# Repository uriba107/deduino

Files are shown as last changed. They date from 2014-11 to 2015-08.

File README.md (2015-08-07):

# DEDUino
Arduino Based DED for Falcon BMS.
Project Blog: http://pits.108vfs.org

## Requirements:
### Hardware:
1. an Arduino or compatible board:
  * Arduino Uno (or compatible)
  * Arduino Micro (or compatible)
  * Arduino Due (or compatible)
  * all similar Arduino/Arduino-like variations (Mega/leonardo/pro Micro) will require code to be adjusted
2. For DED/PFL: One 2.8" or 3.2" 256*64 OLED display (yellow or green), SSD1322 based
  * [BuyDisplay 2.8" yellow on black oled](http://www.buydisplay.com/default/spi-2-8-inch-oled-arduino-256x64-graphic-module-with-pcb-yellow-on-black)
  * [BuyDisplay 3.2" green on black oled](http://www.buydisplay.com/default/spi-oled-manufacturer-256x64-display-panel-supplier-green-on-black)
  * other screens may be also compatible (as long as they are SSD1322 based) - but may require different wiring.
3. For FFI: one 1.3" 128*64 OLED white on black. SSD1306 or SH1106 based
  * [Adafruit 1.3" 128*64 OLED](http://www.adafruit.com/product/938)
  * Generic 1.3" OLED (off the internet), will do fine as long as it's of one of the supported chipsets.
  * Other displays might be also compatible - but may require code edit
4. For Indexers/Caution panel:
  * [PCF8574 8-bit I2C I/O Expander](http://www.ebay.com/sch/sis.html?_nkw=PCF8574P+PCF8574+DIP-16+NXP%2FPHI+Remote+8-bit+I%2FO+Expander+IC) - for Indexers
  * [MCP23017 16-bit I2C I/O Expander](http://www.ebay.com/sch/sis.html?_nkw=MCP23017-E%2FSP+DIP28+16-Bit+I%2FO+Expander+with+I2C+Interface+IC) - optional 16 bit extender (useful for caution panel and other things)
  * LEDs of your choosing (If using attached PCB design unmodified - 5mm pirahna leds are used)
  * Resistors (220-330 ohm reesistors would be a good place to start)
  * Legacy SPI lights are using [74HC595 Shift Register](http://www.adafruit.com/product/450) - you can find them on ebay as well.

### Software:
1. Arduino IDE
2. Windows Vista and up with .net 4.5 installed (XP does not support .net4.5 and I've not tested the supplied connector app with .net4.0)
3. Falcon BMS 4.32+

## How to use:
### Initial setup:
1. Download and install the Arduino IDE (if not already installed)
2. Download the Arduino code
3. In the Arduino IDE - "Add library" choose "U8glib_DEDuino" it's standard U8glib 1.18.1 with 16BIT support enabled (required for the large displays)
4. In "config.h" and uncomment the correct define for your arduino version (Uno, Micro or Due).
5. In "config.h" Uncomment the define statements for the periferials you want to use. please note that adding both DED and PFL may have an impact on performace.
6. Wire prereferials according the the pinout in the code. Please pay attention to the SCK and MOSI pins and the latchpins
7. Upload code to your Arduino.
8. Download the DEDuino Windows app and place it in a folder of your choosing (no installation required)

### running the project:
1. launch DEDuino App
2. Select proper COM port for the arduino to be used and hit "Start"
3. Once connected - Windows app will indicate connected status and all displays and leds should be blanked except for FFI screen that will show "00000".
4. Launch Falcon BMS - As soon as you enter the cockpit, all the instruments connected should display acording to the pit.

## Supported instruments:
1. Displays:
  * DED - Tier 1
  * FFI - Tier 1
  * PFD - Tier 1 (disabled by default due to performance considuration)
2. Lights:
  * Indexers - Tier 1
  * Caution Panel - Tier 1 (Disabled by default due to performance consideration)
3. Future supported instruments:
  * Glareshield lighs - TBD
  * Threat Warning Prime - TBD
  * CMDS - via OLED screen, TBD

## Knows issues:
1. Activating more the one large res display (DED/PFD) will cause performace degradation. Activating more then two might cause noticable lag without further optimization to Arduino code (not yet implemented).
2. "lamp test" might not work properly for Caution panel is some scenarios.
3. When using SPI for driving multiple light arrays, there are issues including freezes, wrongly timed blinks and all sort of wierd shananigans. That is way, I2C is now the primary, prefered protocol for driving lights. SPI support will not be extended, and only retained for comptability.

## PCB
In the PCB folder you would find Eagle files and PDFs with schematics and board drawings. These are the boards I'm working with. You can make them yourself by hand soldering the connectors (see schematics) or source them out to production. All boards were edited using the Free version of Eagle (version 7).

## Enclosures
In the "enclosure" folders you'll find some stractual stuff, like the foamboard DED box.

## Notes and remarks
While the project is OpenSource. Currently I'm holding back the source code for the PC connector application. That is done because The code is a mess, I need to properly document it before I release it. Hopfully sometime this year. Nothing secret about it, promise :)

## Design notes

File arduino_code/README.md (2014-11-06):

## DEDuino - Arduino code
This Is the Arduino side of the project, Licensed under MIT license.

### Usage:
The code contain define statemenst for the three supported Arduino (UNO, Micro and Due).
The code also contains define statmens to all supported featues in this version
#### Available features:
  * Displays: DED, FFI, PFD
  * Lights: Indexers, Caution Panel

#### Default settings (enabled by default):
  * Arduino Uno
  * Displays: DED, FFI
  * Lights: Indexers

#### Known issues:
  * you cannot corrently activate both indexers and caution panel - probably due to the lack of a pull up resistor somewhere. 
  * Lights do not work properly on Due - probably due to a electric design problem - will be solved in future revision.

### Note:
  * Check corresponding wiring diagram in the folder - adjust if needed.
  * Project is using Hardware SPI for best performance - please note that some pins are hardware limited

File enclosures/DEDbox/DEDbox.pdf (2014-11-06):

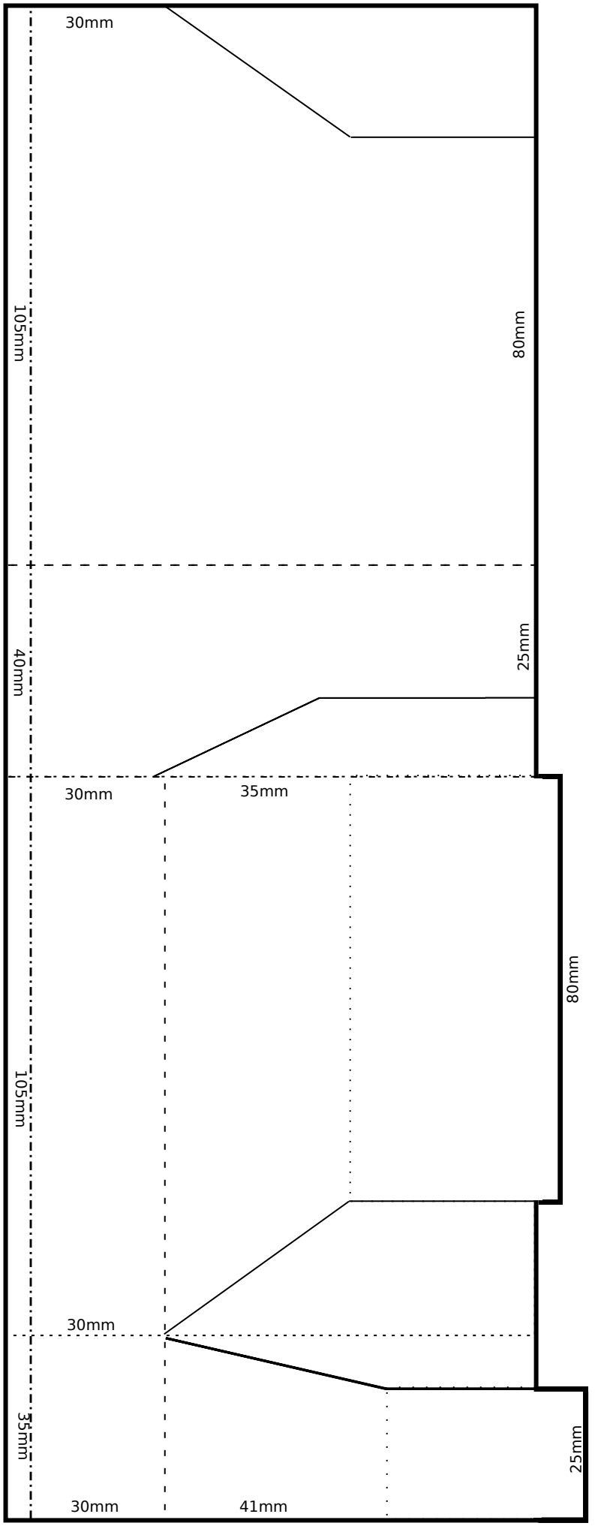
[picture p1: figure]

100mm

285mm

5mm black foamboard

# DED Box

Uri Ben-Avraham 2014

Cut
Folded
(inner)
Folded
(Outer)
Groove

## Legend

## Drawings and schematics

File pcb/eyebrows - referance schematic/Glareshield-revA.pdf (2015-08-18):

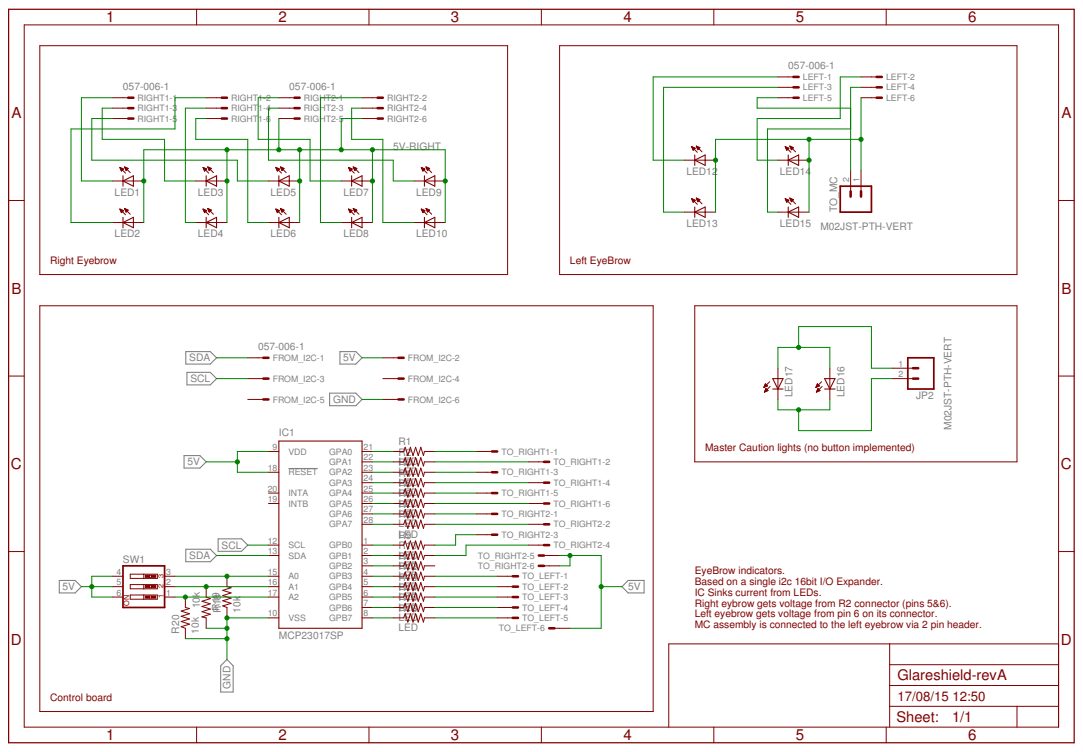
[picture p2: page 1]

Master Caution lights (no button implemented)

IC Sinks current from LEDs. Right eybrow gets voltage from R2 connector (pins 5&6). Left eyebrow gets voltage from pin 6 on its connector. MC assembly is connected to the left eyebrow via 2 pin header. 1 2 3 ON

EyeBrow indicators. Based on a single i2c 16bit I/O Expander.

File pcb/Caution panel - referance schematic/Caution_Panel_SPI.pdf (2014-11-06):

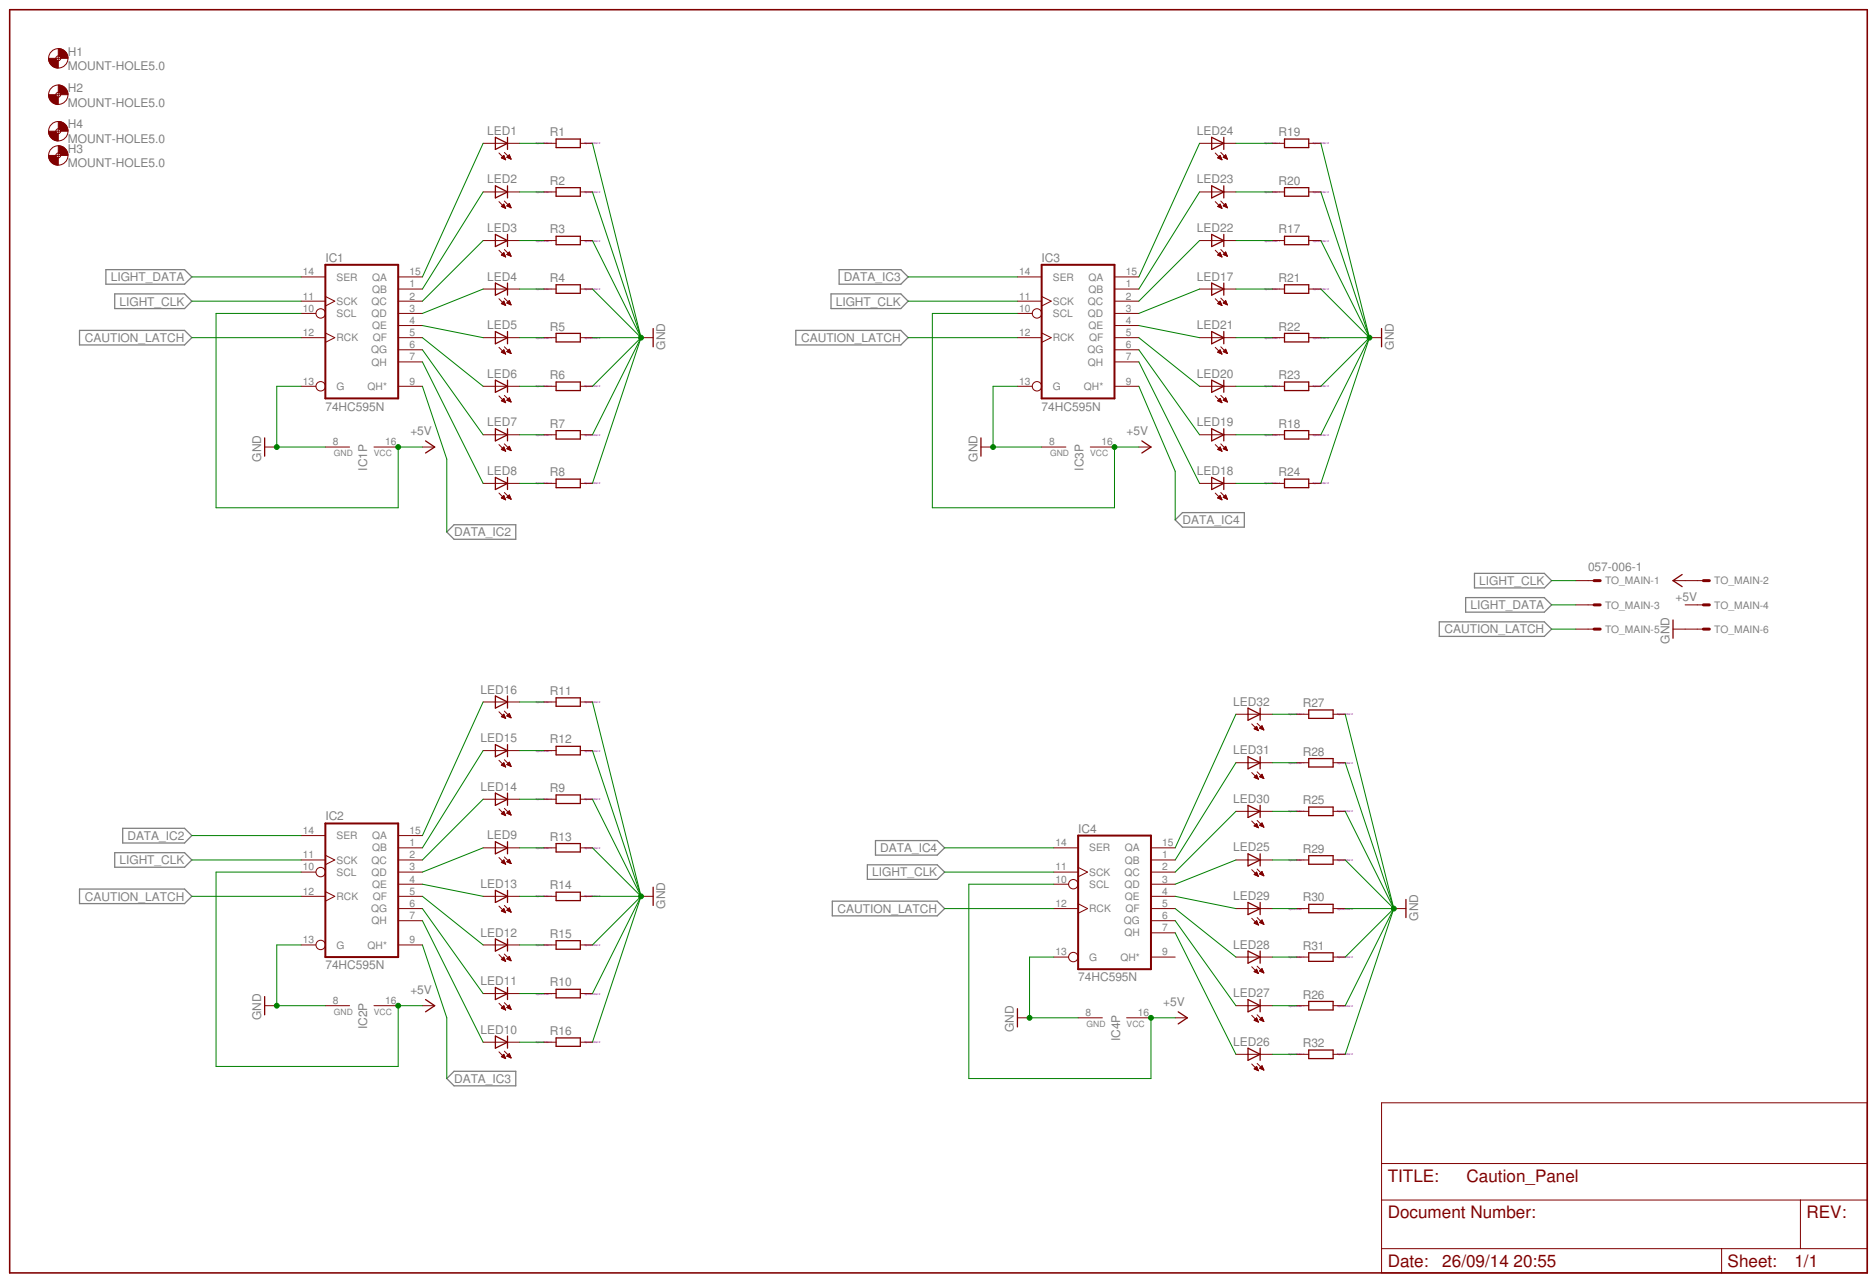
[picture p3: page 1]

MOUNT-HOLE5.0 MOUNT-HOLE5.0

REV: TITLE: Document Number: Caution_Panel

Date: 26/09/14 20:55 | Sheet: 1/1

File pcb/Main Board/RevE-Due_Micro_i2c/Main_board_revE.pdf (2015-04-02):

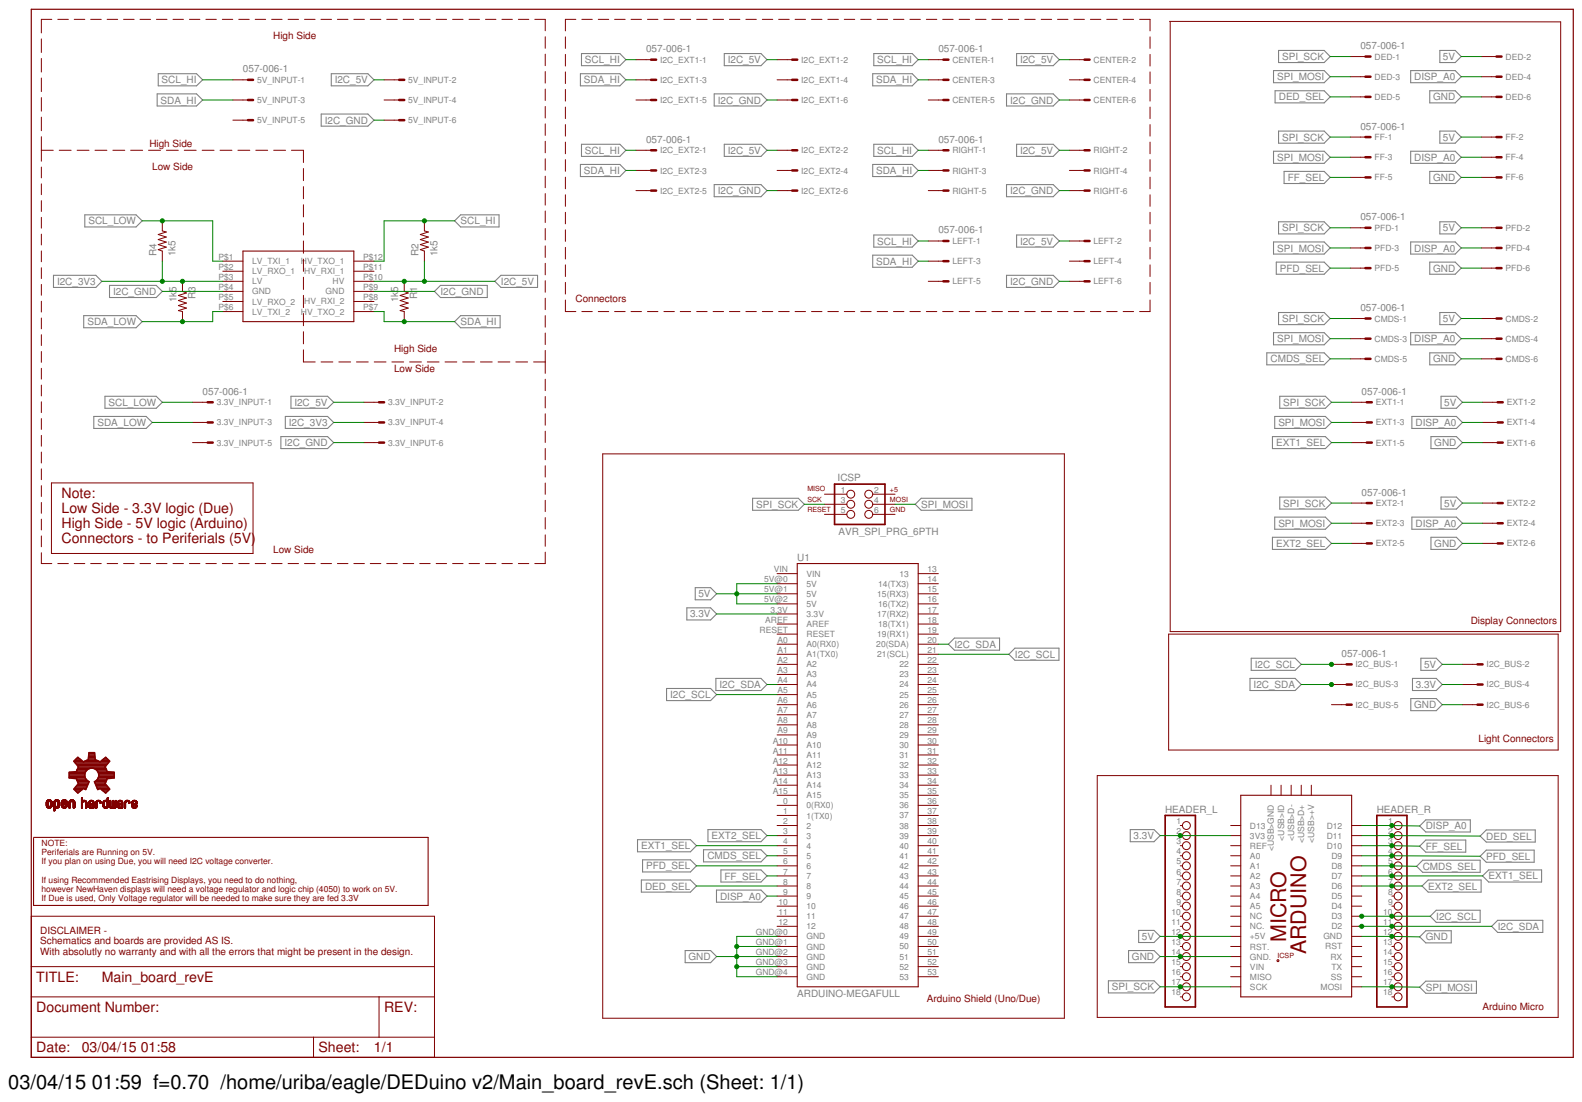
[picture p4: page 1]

Low Side High Side

Note: Low Side - 3.3V logic (Due)
High Side - 5V logic (Arduino)
Connectors - to Periferials (5V)

NOTE: Periferials are Running on 5V.
If you plan on using Due, you will need I2C voltage converter.
If using Recommended Eastrising Displays, you need to do nothing, however NewHaven displays will need a voltage regulator and logic chip (4050) to work on 5V.
If Due is used, Only Voltage regulator will be needed to make sure they are fed 3.3V

DISCLAIMER - Schematics and boards are provided AS IS. With absolutly no warranty and with all the errors that might be present in the design.

REV: TITLE: Document Number: Main_board_revE

Date: 03/04/15 01:58 | Sheet: 1/1

03/04/15 01:59 f=0.70 /home/uriba/eagle/DEDuino v2/Main_board_revE.sch (Sheet: 1/1)

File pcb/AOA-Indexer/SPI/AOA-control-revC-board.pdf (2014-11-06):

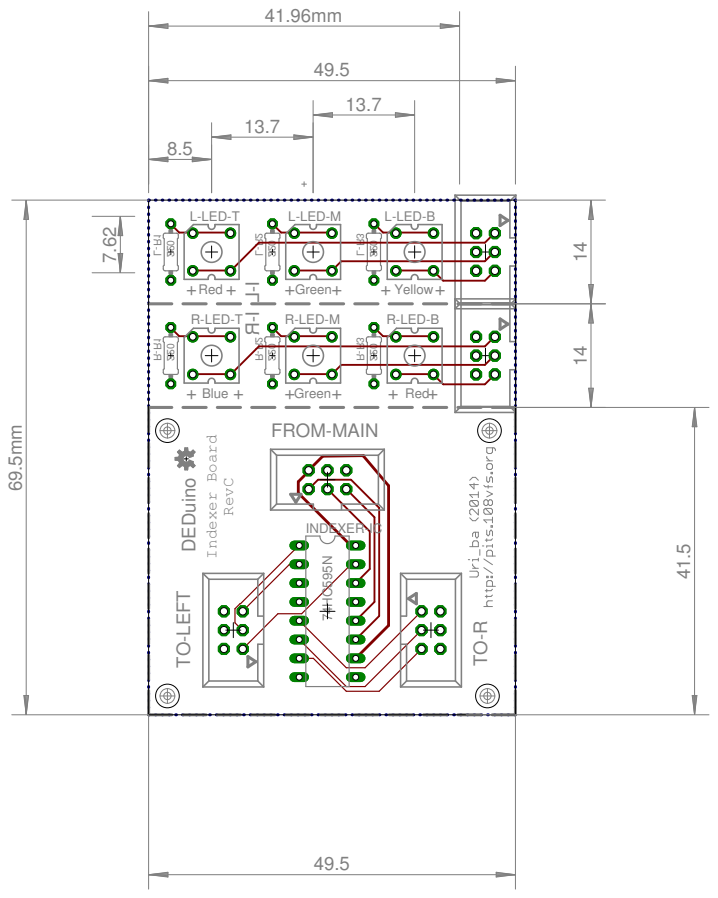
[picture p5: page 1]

220 220 220 220 220 220 I-L L-R1 I-R R-R1 R-R2 R-R3 L-R2 L-R3 + + + + + + + + + + + + Indexer Board RevC DEDuino FROM-MAIN TO-LEFT TO-R INDEXER-IC L-LED-T L-LED-M L-LED-B R-LED-T R-LED-M R-LED-B 74HC595N Red Green Yellow Blue Green Red 41.5 49.5 14 14 69.5mm 8.5 13.7 49.5 7.62 41.96mm 13.7

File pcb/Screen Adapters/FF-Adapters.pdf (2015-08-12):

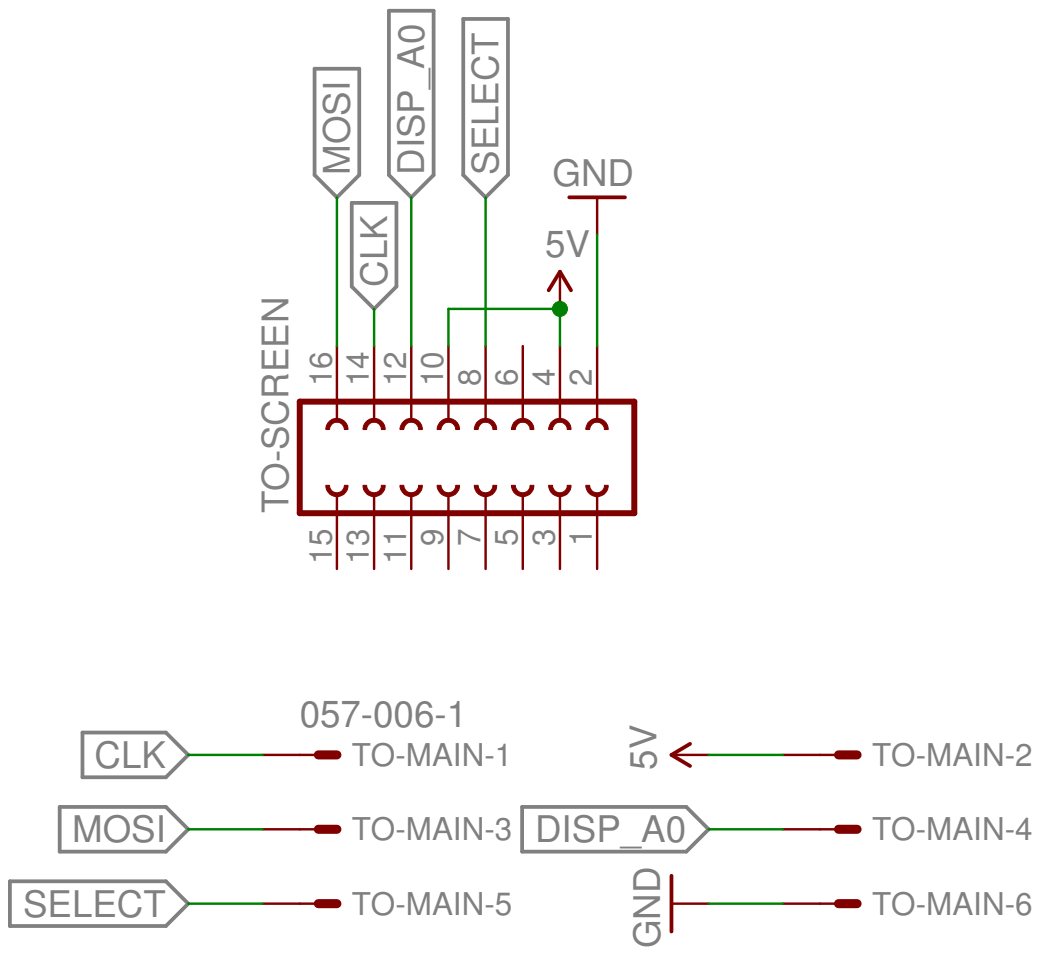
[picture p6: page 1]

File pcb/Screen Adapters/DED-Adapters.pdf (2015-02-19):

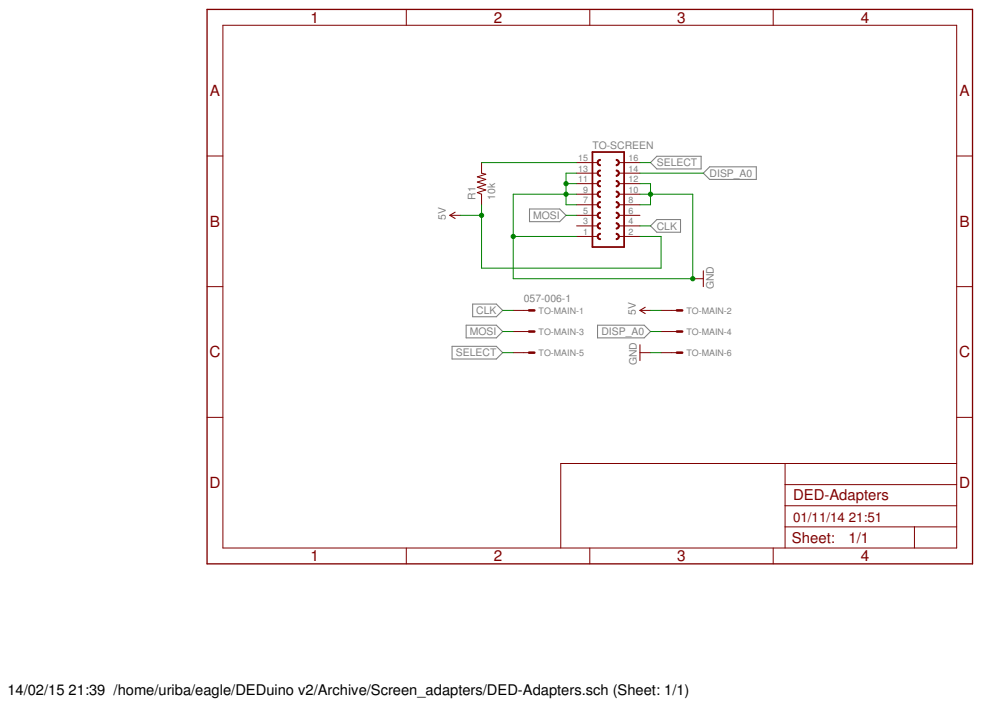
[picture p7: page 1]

10k TO-MAIN-1 TO-MAIN-2 TO-MAIN-3 TO-MAIN-4 TO-MAIN-5 TO-MAIN-6

14/02/15 21:39 /home/uriba/eagle/DEDuino v2/Archive/Screen_adapters/DED-Adapters.sch (Sheet: 1/1)

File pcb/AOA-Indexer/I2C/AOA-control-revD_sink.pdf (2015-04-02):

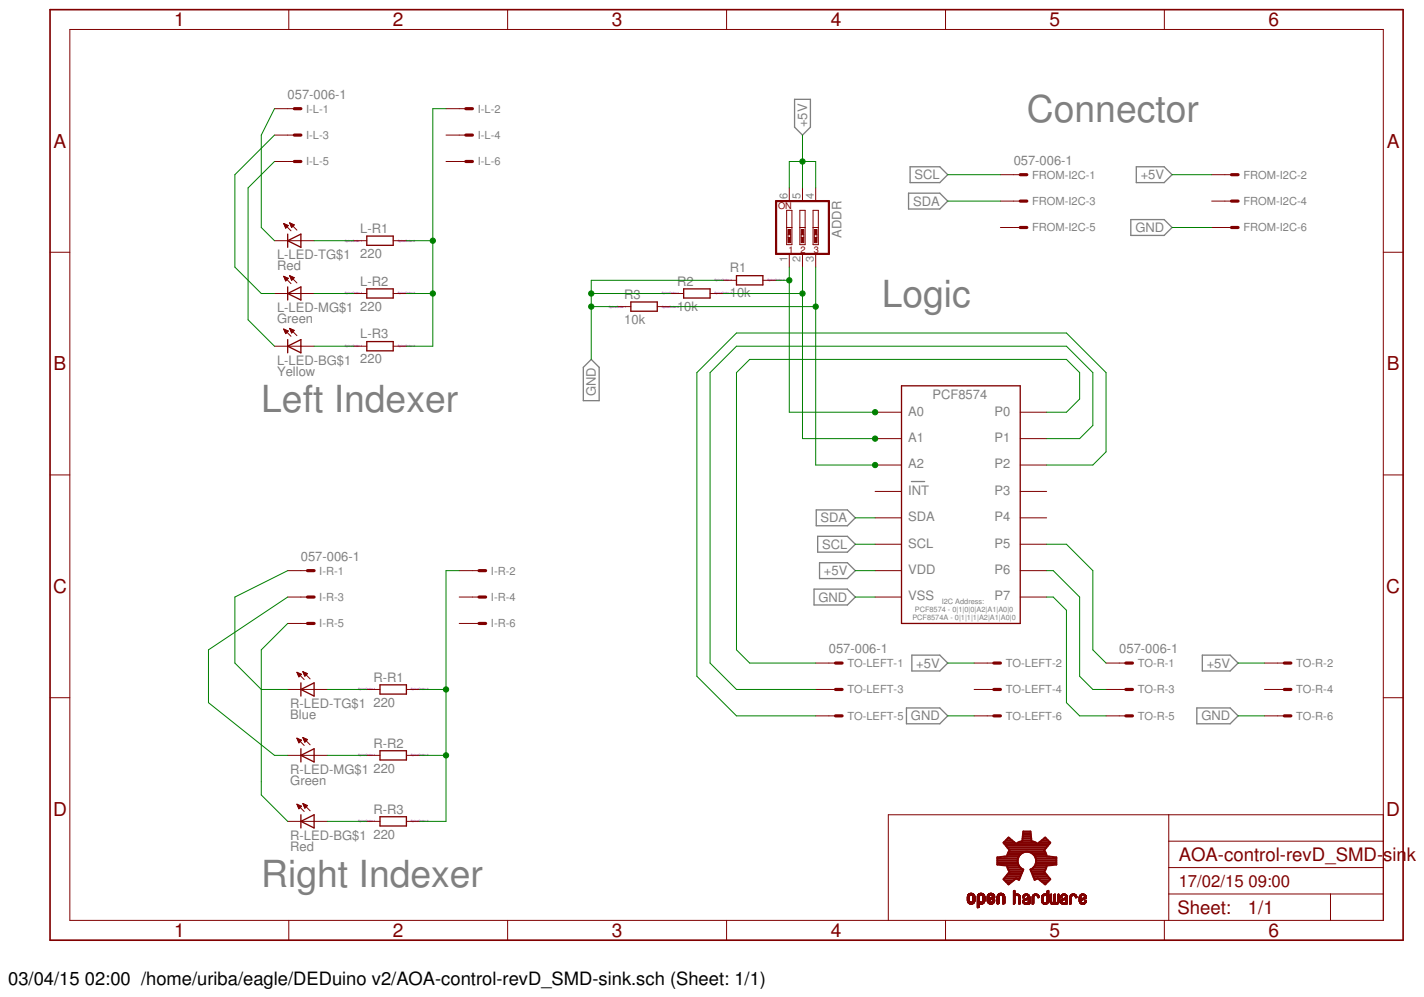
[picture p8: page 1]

03/04/15 02:00 /home/uriba/eagle/DEDuino v2/AOA-control-revD_SMD-sink.sch (Sheet: 1/1)

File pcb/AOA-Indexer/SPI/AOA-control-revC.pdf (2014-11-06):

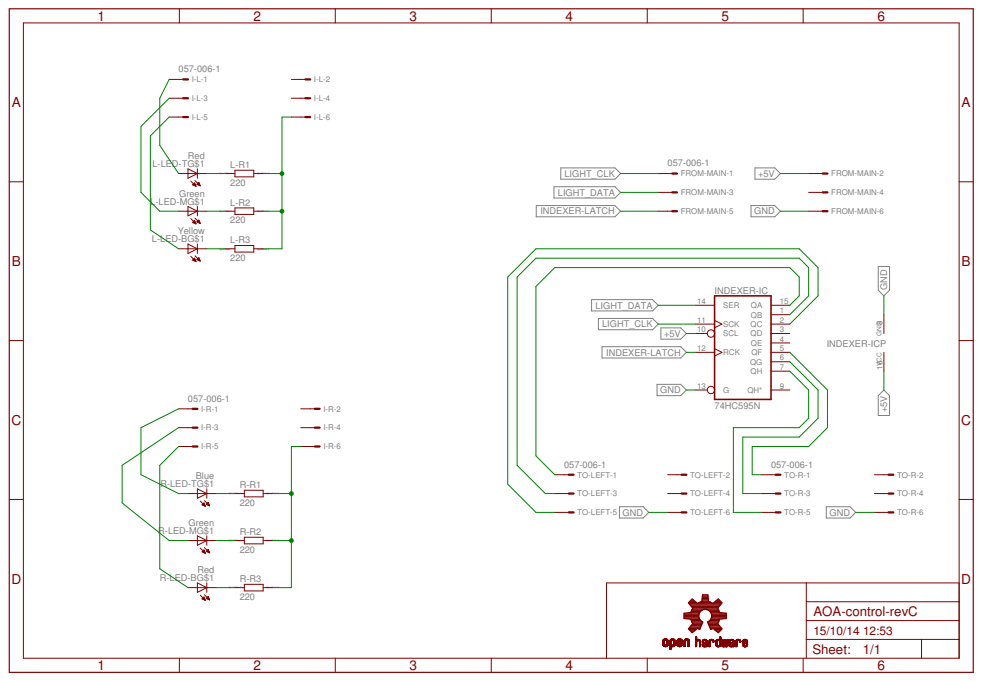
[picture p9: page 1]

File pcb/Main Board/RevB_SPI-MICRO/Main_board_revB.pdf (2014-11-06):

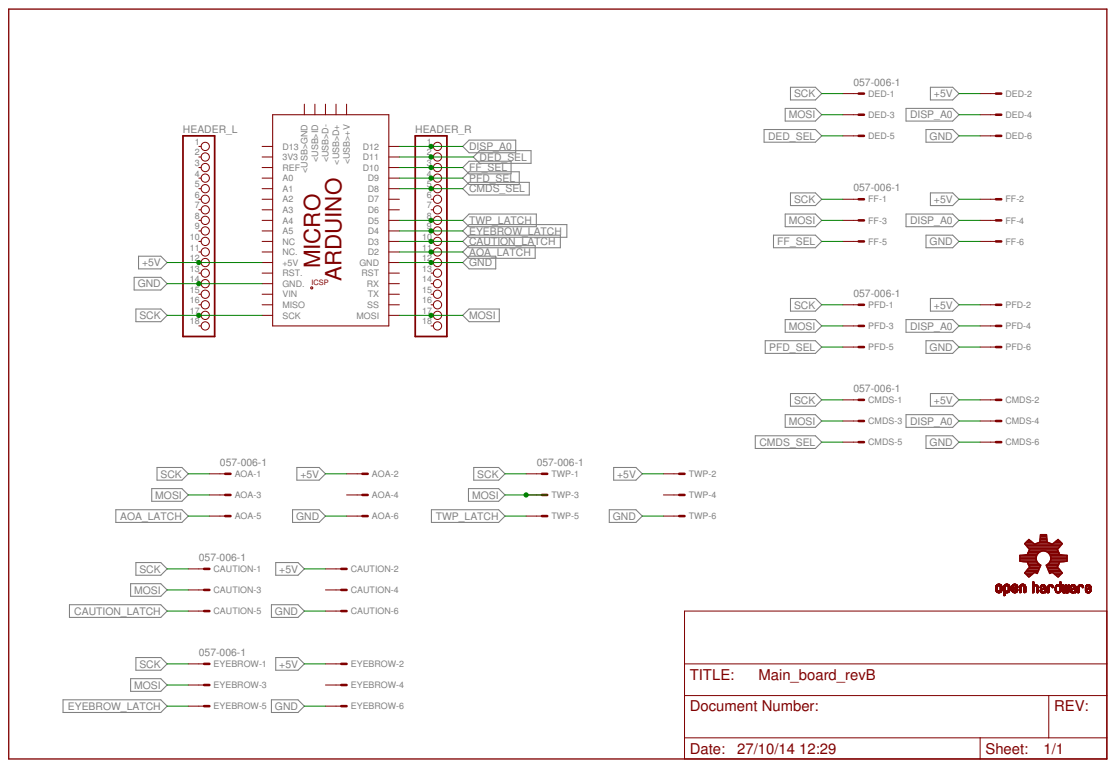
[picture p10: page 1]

3 4 5 6 7 8 9 10 11 12 13 14 15 16 17 18 | DED_SEL

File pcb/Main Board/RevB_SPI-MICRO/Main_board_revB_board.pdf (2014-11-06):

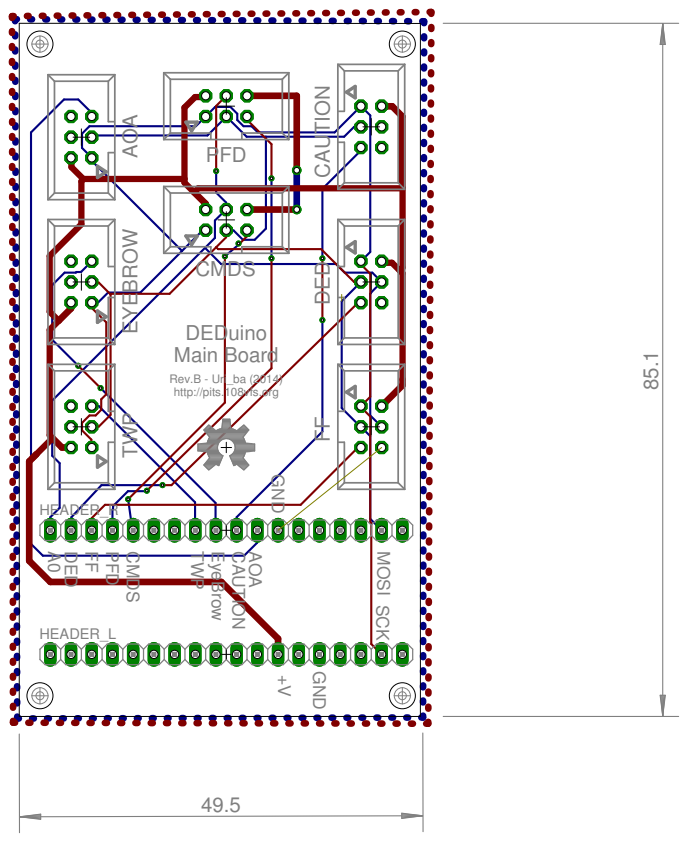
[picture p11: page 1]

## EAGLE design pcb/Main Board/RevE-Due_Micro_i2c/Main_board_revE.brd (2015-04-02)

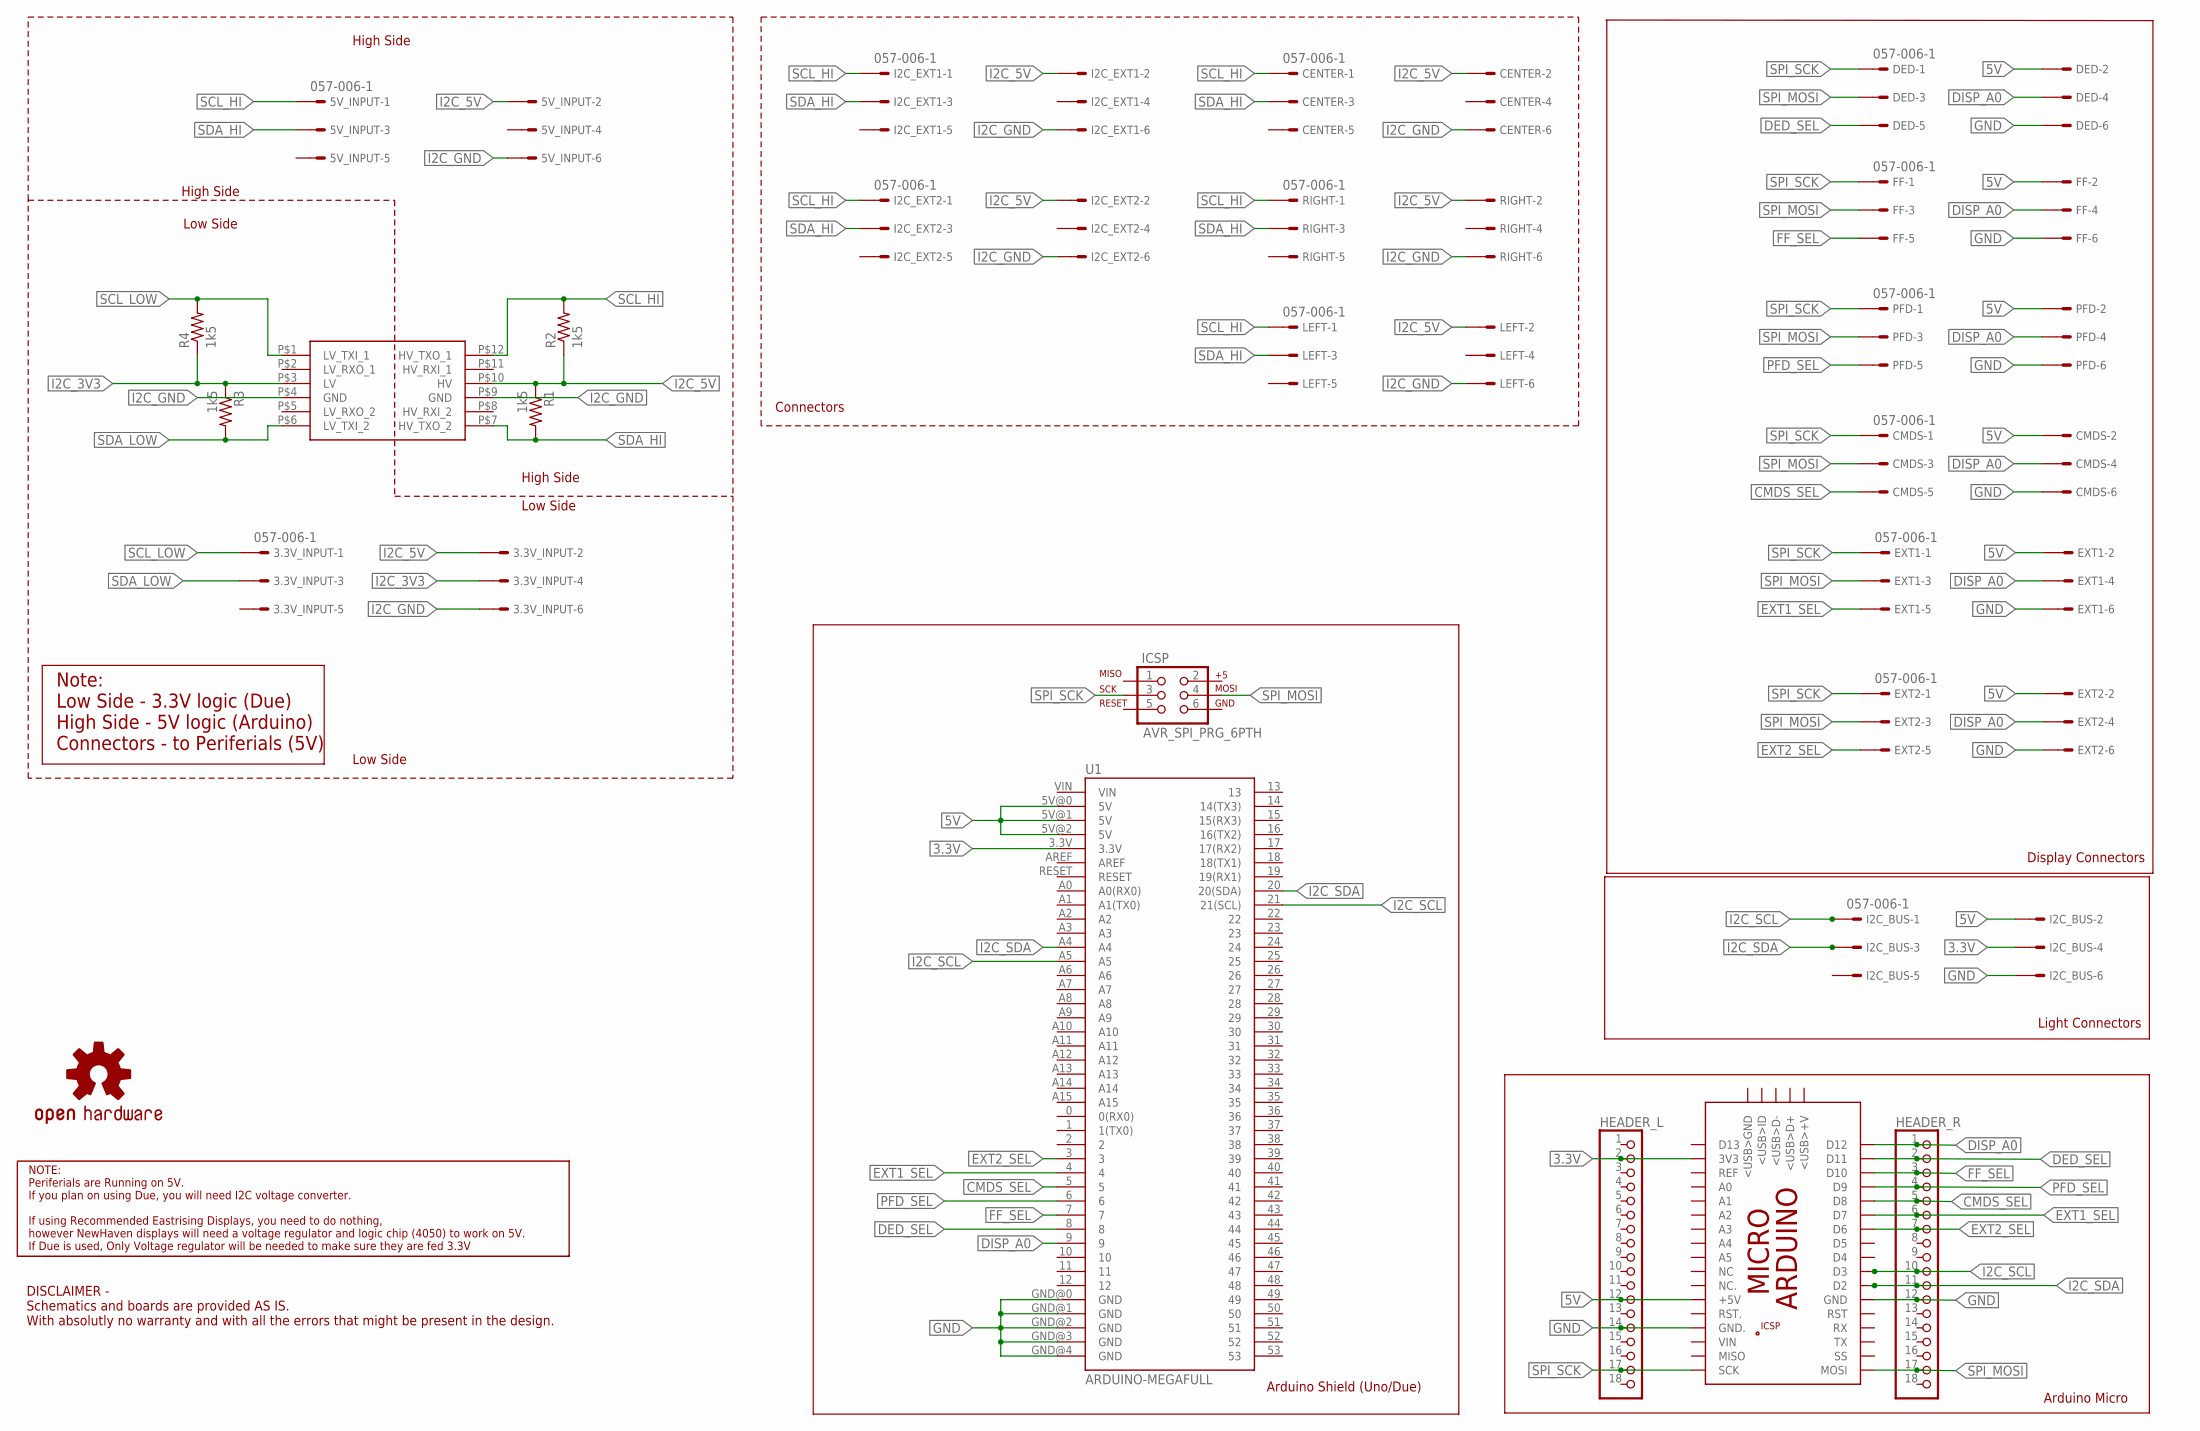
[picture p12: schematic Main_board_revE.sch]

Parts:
3.3V_INPUT, 5V_INPUT: 057-006-1
CENTER: 057-006-1
CMDS: 057-006-1
DED: 057-006-1
EXT1, EXT2: 057-006-1
FF: 057-006-1
HEADER_L: PINHD-1X18; 1X18
HEADER_R: PINHD-1X18; 1X18
I2C_BUS, I2C_EXT1, I2C_EXT2: 057-006-1
ICSP: AVR_SPI_PRG_6PTH; 2X3
LEFT: 057-006-1
LOGO1: OSHW-LOGOM; OSHW-LOGO-M
PFD: 057-006-1
R1, R2, R3, R4: 1k5; 0805
RIGHT: 057-006-1
U1: ARDUINO-MEGAFULL; ARDUINO_MEGA
U$1: LOGIC_LEVEL_CONVERTER

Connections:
3.3V: HEADER_L.2, I2C_BUS.4, U1.3.3V
5V: CMDS.2, DED.2, EXT1.2, EXT2.2, FF.2, HEADER_L.12, I2C_BUS.2, PFD.2, U1.5V@0 (5V), U1.5V@1 (5V), U1.5V@2 (5V)
CMDS_SEL: CMDS.5, HEADER_R.5, U1.5
DED_SEL: DED.5, HEADER_R.2, U1.8
DISP_A0: CMDS.4, DED.4, EXT1.4, EXT2.4, FF.4, HEADER_R.1, PFD.4, U1.9
EXT1_SEL: EXT1.5, HEADER_R.6, U1.4
EXT2_SEL: EXT2.5, HEADER_R.7, U1.3
FF_SEL: FF.5, HEADER_R.3, U1.7
GND: CMDS.6, DED.6, EXT1.6, EXT2.6, FF.6, HEADER_L.14, HEADER_R.12, I2C_BUS.6, PFD.6, U1.GND@0 (GND), U1.GND@1 (GND), U1.GND@2 (GND), U1.GND@3 (GND), U1.GND@4 (GND)
I2C_3V3: 3.3V_INPUT.4, R3.1, R4.1, U$1.P$3 (LV)
I2C_5V: 3.3V_INPUT.2, 5V_INPUT.2, CENTER.2, I2C_EXT1.2, I2C_EXT2.2, LEFT.2, R1.1, R2.1, RIGHT.2, U$1.P$10 (HV)
I2C_GND: 3.3V_INPUT.6, 5V_INPUT.6, CENTER.6, I2C_EXT1.6, I2C_EXT2.6, LEFT.6, RIGHT.6, U$1.P$4 (GND), U$1.P$9 (GND)
I2C_SCL: HEADER_R.10, I2C_BUS.1, U1.21 (21(SCL)), U1.A5
I2C_SDA: HEADER_R.11, I2C_BUS.3, U1.20 (20(SDA)), U1.A4
PFD_SEL: HEADER_R.4, PFD.5, U1.6
SCL_HI: 5V_INPUT.1, CENTER.1, I2C_EXT1.1, I2C_EXT2.1, LEFT.1, R2.2, RIGHT.1, U$1.P$12 (HV_TXO_1)
SCL_LOW: 3.3V_INPUT.1, R4.2, U$1.P$1 (LV_TXI_1)
SDA_HI: 5V_INPUT.3, CENTER.3, I2C_EXT1.3, I2C_EXT2.3, LEFT.3, R1.2, RIGHT.3, U$1.P$7 (HV_TXO_2)
SDA_LOW: 3.3V_INPUT.3, R3.2, U$1.P$6 (LV_TXI_2)
SPI_MOSI: CMDS.3, DED.3, EXT1.3, EXT2.3, FF.3, HEADER_R.17, ICSP.4, PFD.3
SPI_SCK: CMDS.1, DED.1, EXT1.1, EXT2.1, FF.1, HEADER_L.17, ICSP.3, PFD.1

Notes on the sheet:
Arduino Shield (Uno/Due)
Arduino Micro
Light Connectors
Display Connectors
DISCLAIMER - Schematics and boards are provided AS IS. With absolutly no warranty and with all the errors that might be present in the design.
NOTE: Periferials are Running on 5V. If you plan on using Due, you will need I2C voltage converter. If using Recommended Eastrising Displays, you need to do nothing, however NewHaven displays will need a voltage regulator and logic chip (4050) to work on 5V. If Due is used, Only Voltage regulator w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
Low Side
High Side
Connectors
Note: Low Side - 3.3V logic (Due) High Side - 5V logic (Arduino) Connectors - to Periferials (5V)

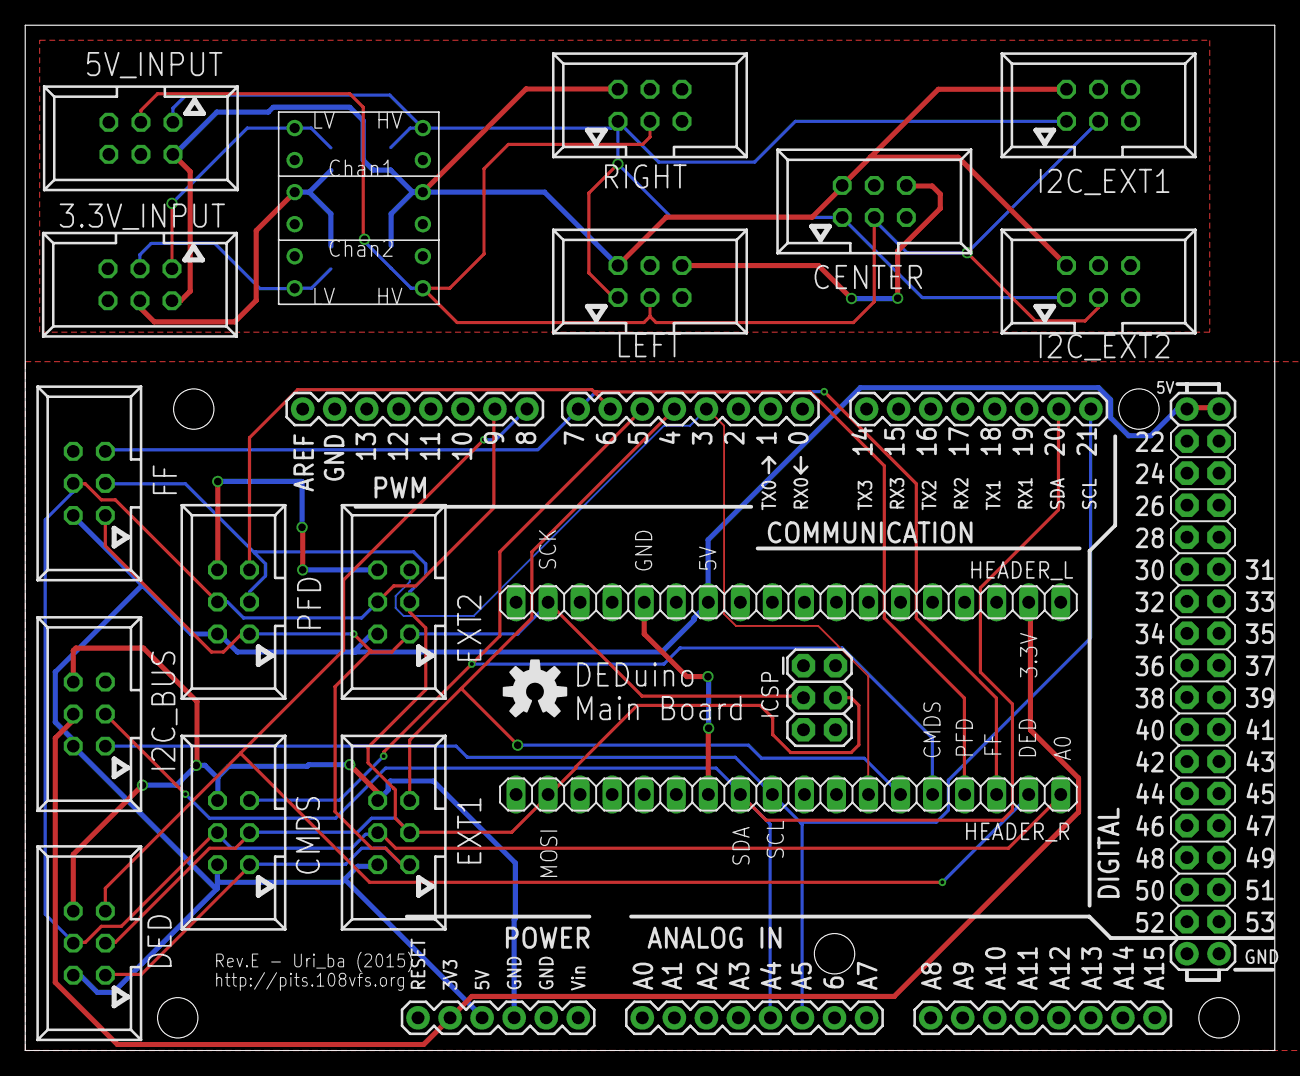
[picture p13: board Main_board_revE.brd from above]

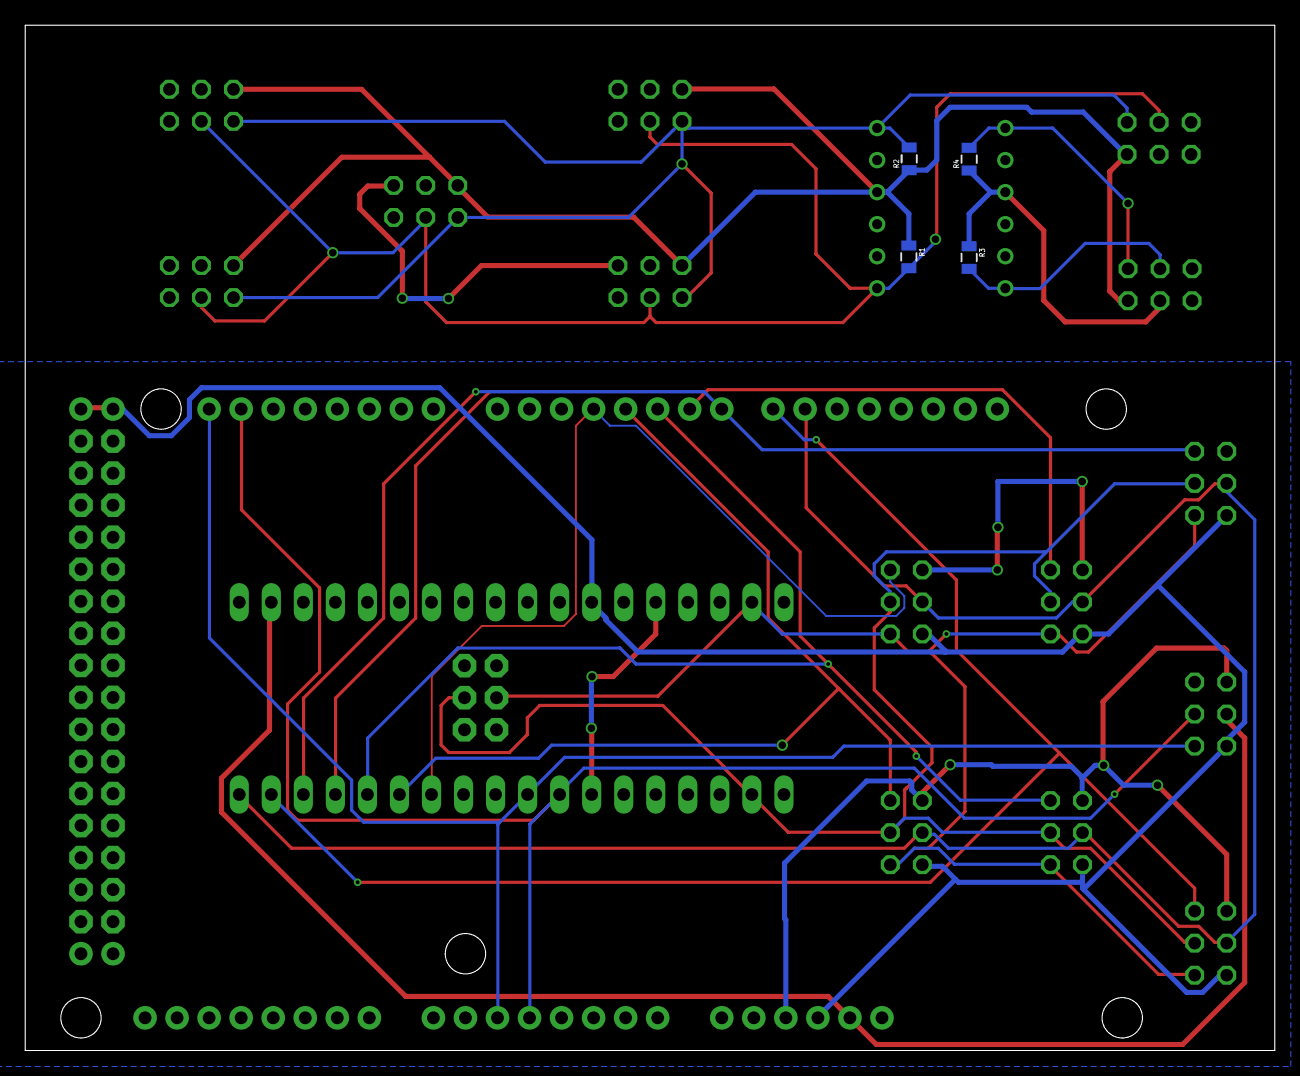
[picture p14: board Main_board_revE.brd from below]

Board: 2 copper layers, 99.1 x 81.3 mm, 24 parts (4 on the bottom side), 21 nets.

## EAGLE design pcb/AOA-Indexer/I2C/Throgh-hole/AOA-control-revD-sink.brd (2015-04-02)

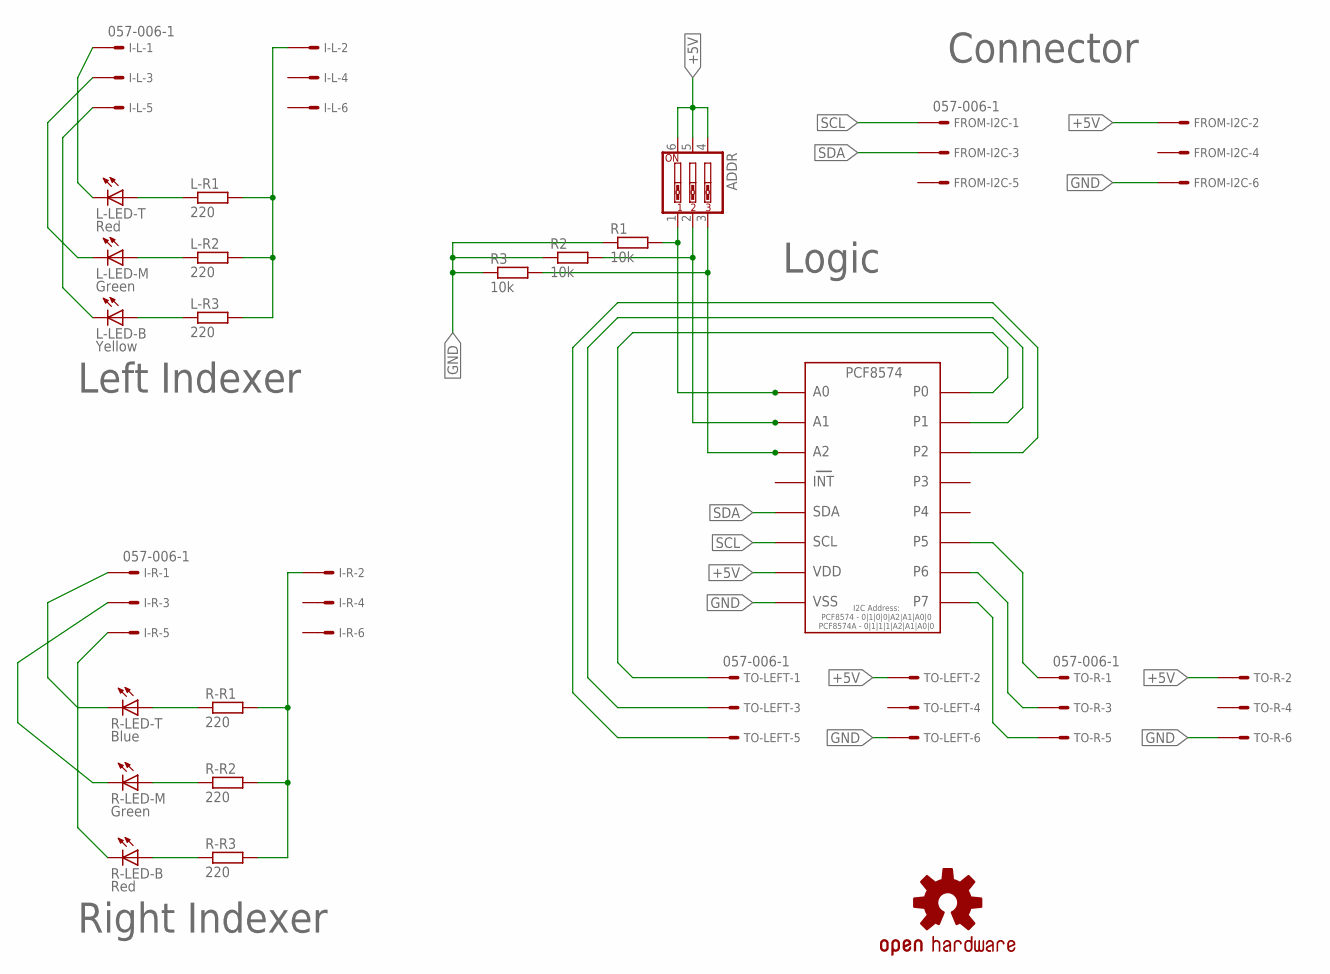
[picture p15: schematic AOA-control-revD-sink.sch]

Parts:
ADDR: SW_DIP-3; EDG-03
FROM-I2C: 057-006-1
I-L: 057-006-1
I-R: 057-006-1
L-LED-B: Yellow; CP41B
L-LED-M: Green; CP41B
L-LED-T: Red; CP41B
L-R1, L-R2, L-R3: 220; 0204/7
LOGO1: OSHW-LOGOS; OSHW-LOGO-S
R1, R2, R3: 10k; 0204/7
R-LED-B: Red; CP41B
R-LED-M: Green; CP41B
R-LED-T: Blue; CP41B
R-R1, R-R2, R-R3: 220; 0204/7
TO-LEFT: 057-006-1
TO-R: 057-006-1
U$1: PCF8574P/AP; DIP16

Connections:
5V-L: I-L.2, L-R1.2, L-R2.2, L-R3.2
5V-R: I-R.2, R-R1.2, R-R2.2, R-R3.2
+5V: ADDR.4, ADDR.5, ADDR.6, FROM-I2C.2, TO-LEFT.2, TO-R.2, U$1.VDD
A0: ADDR.1, R1.2, U$1.A0
A1: ADDR.2, R2.2, U$1.A1
A2: ADDR.3, R3.2, U$1.A2
GND: FROM-I2C.6, R1.1, R2.1, R3.1, TO-LEFT.6, TO-R.6, U$1.VSS
unnamed: I-L.1, L-LED-T.1 (C), L-LED-T.4 (C)
unnamed: I-L.3, L-LED-M.1 (C), L-LED-M.4 (C)
unnamed: I-L.5, L-LED-B.1 (C), L-LED-B.4 (C)
unnamed: R-LED-B.2 (A), R-LED-B.3 (A), R-R3.1
unnamed: I-R.1, R-LED-T.1 (C), R-LED-T.4 (C)
unnamed: I-R.3, R-LED-M.1 (C), R-LED-M.4 (C)
unnamed: I-R.5, R-LED-B.1 (C), R-LED-B.4 (C)
unnamed: R-LED-M.2 (A), R-LED-M.3 (A), R-R2.1
unnamed: R-LED-T.2 (A), R-LED-T.3 (A), R-R1.1
unnamed: L-LED-T.2 (A), L-LED-T.3 (A), L-R1.1
unnamed: TO-LEFT.1, U$1.P0
unnamed: L-LED-M.2 (A), L-LED-M.3 (A), L-R2.1
unnamed: L-LED-B.2 (A), L-LED-B.3 (A), L-R3.1
unnamed: TO-LEFT.3, U$1.P1
unnamed: TO-LEFT.5, U$1.P2
unnamed: TO-R.1, U$1.P5
unnamed: TO-R.3, U$1.P6
unnamed: TO-R.5, U$1.P7
SCL: FROM-I2C.1, U$1.SCL
SDA: FROM-I2C.3, U$1.SDA

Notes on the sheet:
Connector
Logic
Left Indexer
Right Indexer

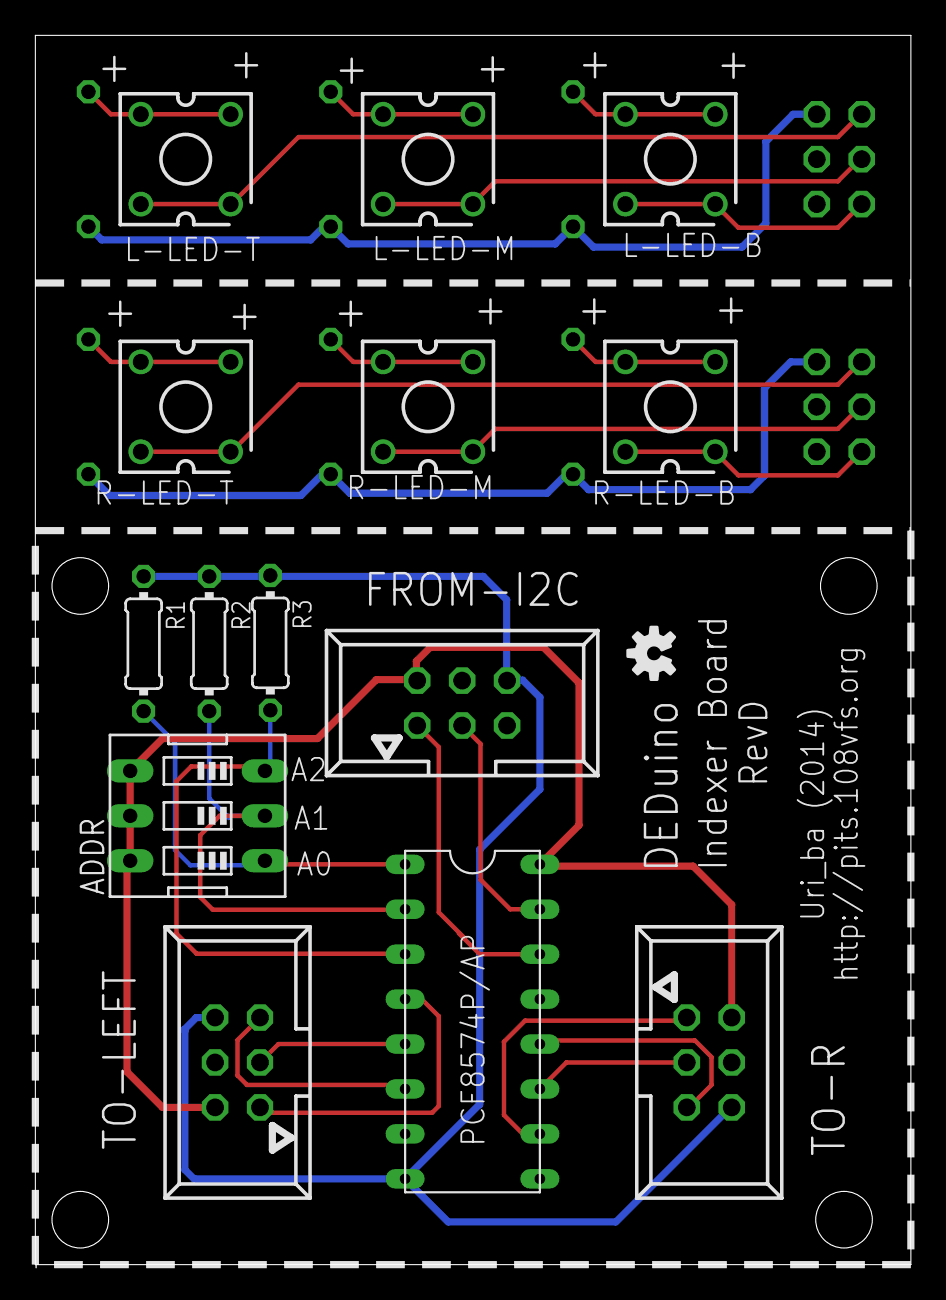
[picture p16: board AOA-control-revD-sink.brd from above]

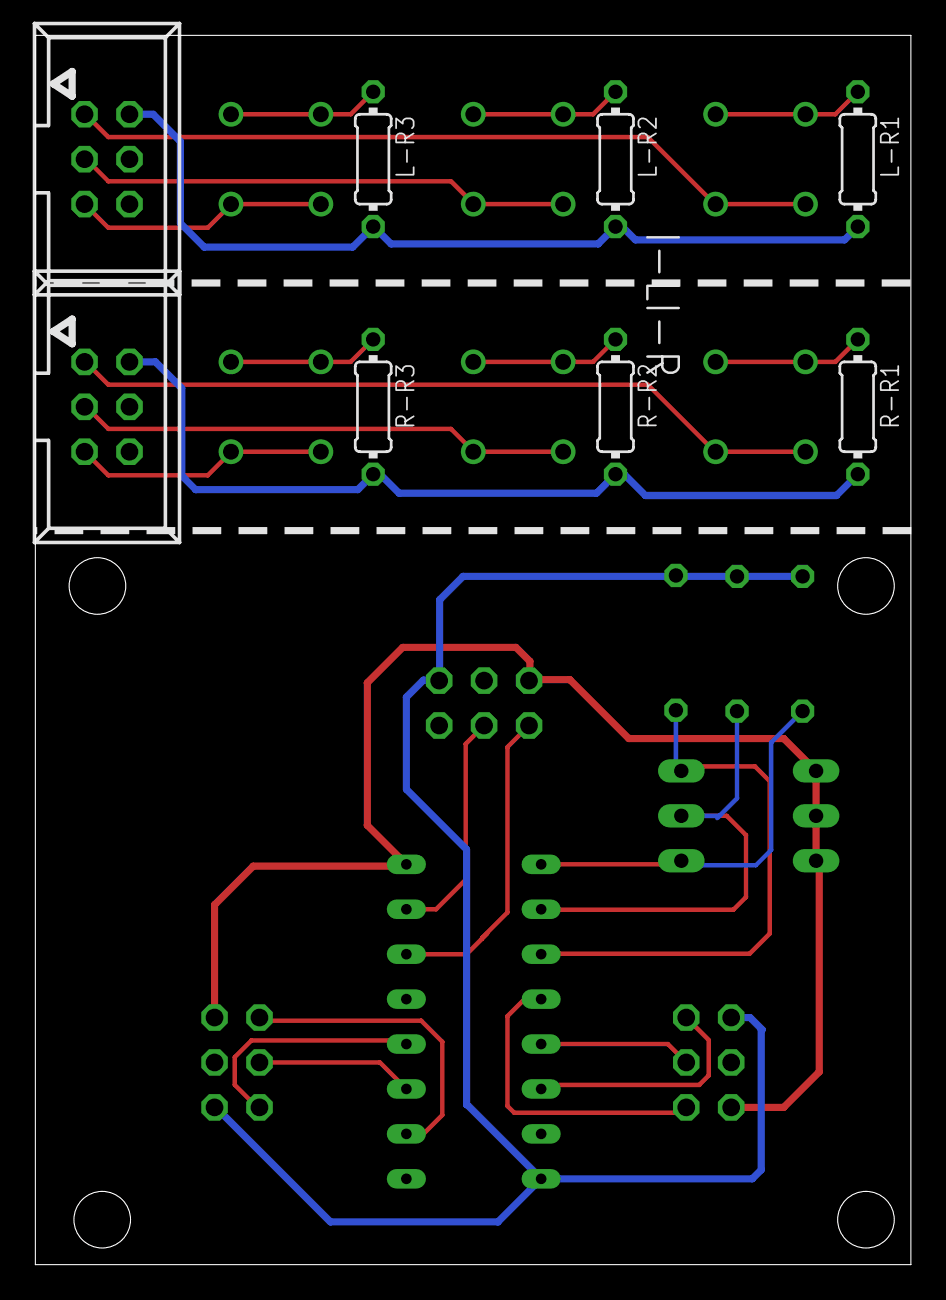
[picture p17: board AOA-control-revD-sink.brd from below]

Board: 2 copper layers, 49.5 x 69.5 mm, 23 parts (8 on the bottom side), 27 nets.

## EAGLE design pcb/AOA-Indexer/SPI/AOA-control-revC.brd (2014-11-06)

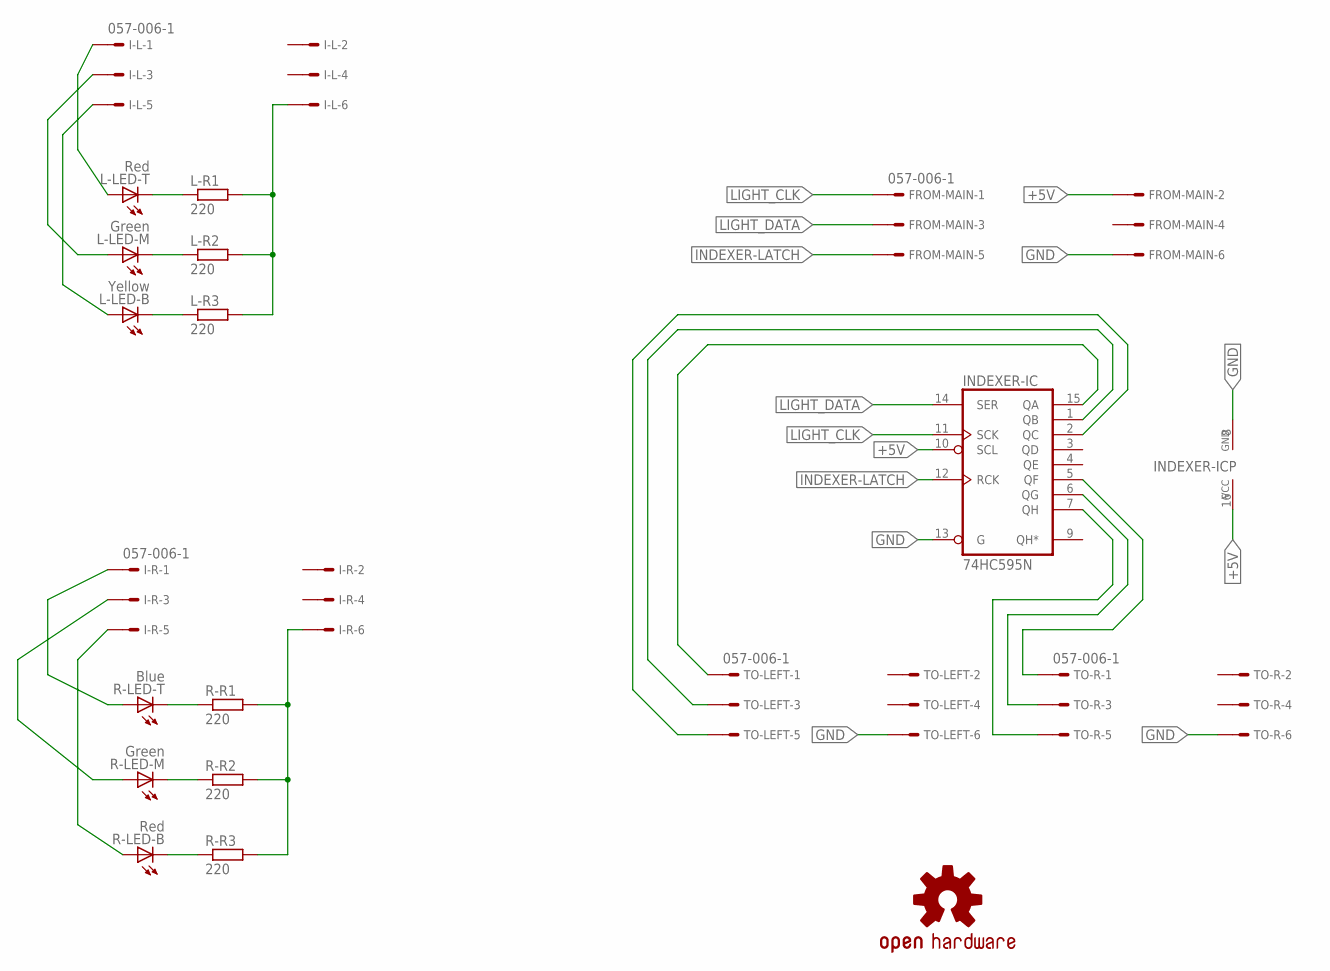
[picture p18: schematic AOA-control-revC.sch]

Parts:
FROM-MAIN: 057-006-1
I-L: 057-006-1
I-R: 057-006-1
INDEXER-IC: 74HC595N; DIL16
L-LED-B: Yellow; CP41B
L-LED-M: Green; CP41B
L-LED-T: Red; CP41B
L-R1, L-R2, L-R3: 220; 0204/7
LOGO1: OSHW-LOGOS; OSHW-LOGO-S
R-LED-B: Red; CP41B
R-LED-M: Green; CP41B
R-LED-T: Blue; CP41B
R-R1, R-R2, R-R3: 220; 0204/7
TO-LEFT: 057-006-1
TO-R: 057-006-1

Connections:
+5V: FROM-MAIN.2, INDEXER-IC.10 (SCL), INDEXER-IC.16 (VCC)
GND: FROM-MAIN.6, I-L.6, I-R.6, INDEXER-IC.8 (GND), INDEXER-IC.13 (G), L-R1.2, L-R2.2, L-R3.2, R-R1.2, R-R2.2, R-R3.2, TO-LEFT.6, TO-R.6
INDEXER-LATCH: FROM-MAIN.5, INDEXER-IC.12 (RCK)
L-B: INDEXER-IC.2 (QC), TO-LEFT.5
L-M: INDEXER-IC.1 (QB), TO-LEFT.3
L-T: INDEXER-IC.15 (QA), TO-LEFT.1
LIGHT_CLK: FROM-MAIN.1, INDEXER-IC.11 (SCK)
LIGHT_DATA: FROM-MAIN.3, INDEXER-IC.14 (SER)
unnamed: I-L.1, L-LED-T.2 (A), L-LED-T.3 (A)
unnamed: I-L.3, L-LED-M.2 (A), L-LED-M.3 (A)
unnamed: I-L.5, L-LED-B.2 (A), L-LED-B.3 (A)
unnamed: R-LED-B.1 (C), R-LED-B.4 (C), R-R3.1
unnamed: I-R.1, R-LED-T.2 (A), R-LED-T.3 (A)
unnamed: I-R.3, R-LED-M.2 (A), R-LED-M.3 (A)
unnamed: I-R.5, R-LED-B.2 (A), R-LED-B.3 (A)
unnamed: L-LED-B.1 (C), L-LED-B.4 (C), L-R3.1
unnamed: L-LED-M.1 (C), L-LED-M.4 (C), L-R2.1
unnamed: L-LED-T.1 (C), L-LED-T.4 (C), L-R1.1
unnamed: R-LED-M.1 (C), R-LED-M.4 (C), R-R2.1
unnamed: R-LED-T.1 (C), R-LED-T.4 (C), R-R1.1
R-B: INDEXER-IC.7 (QH), TO-R.5
R-M: INDEXER-IC.6 (QG), TO-R.3
R-T: INDEXER-IC.5 (QF), TO-R.1

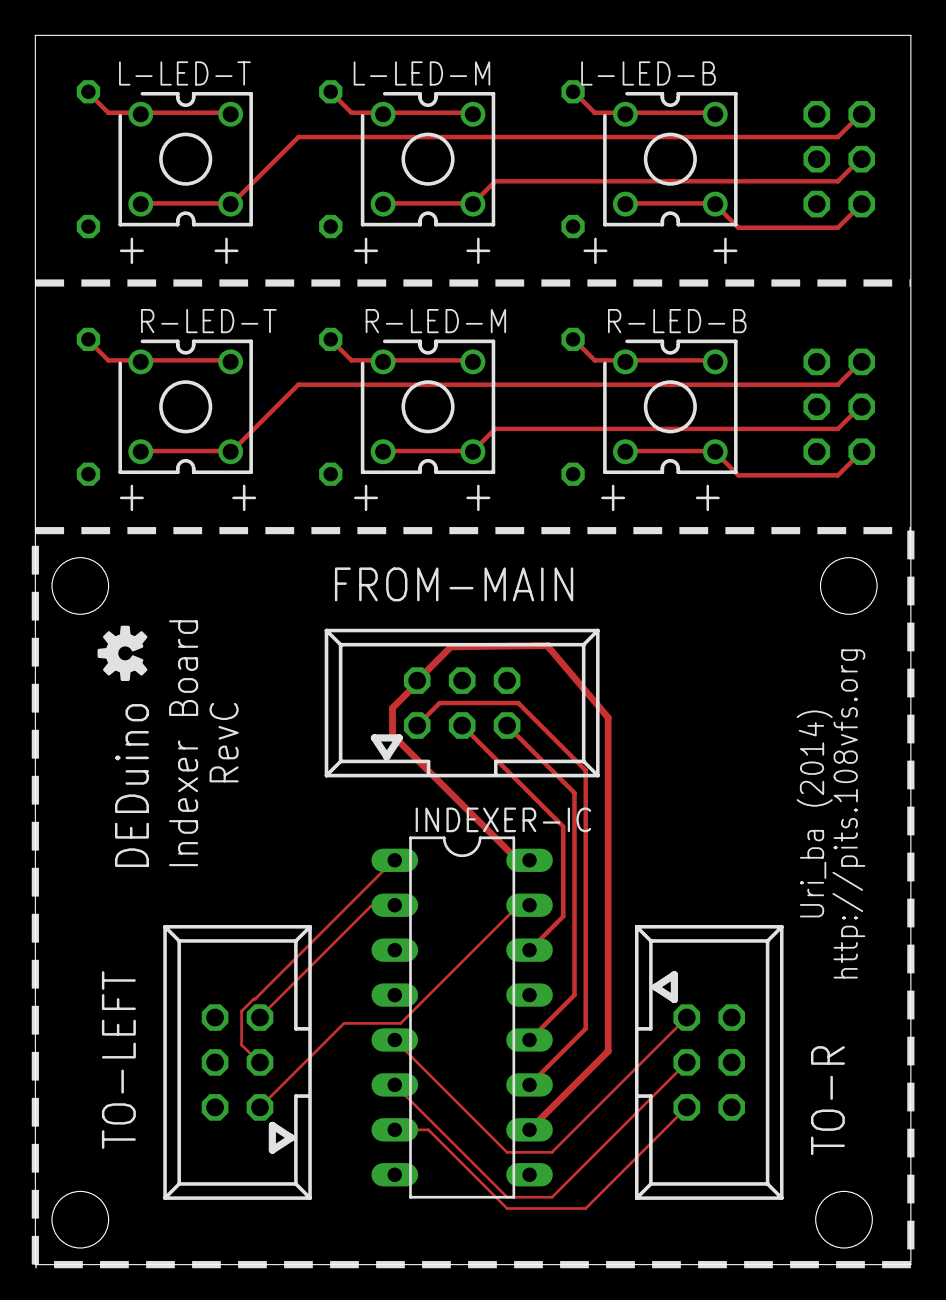
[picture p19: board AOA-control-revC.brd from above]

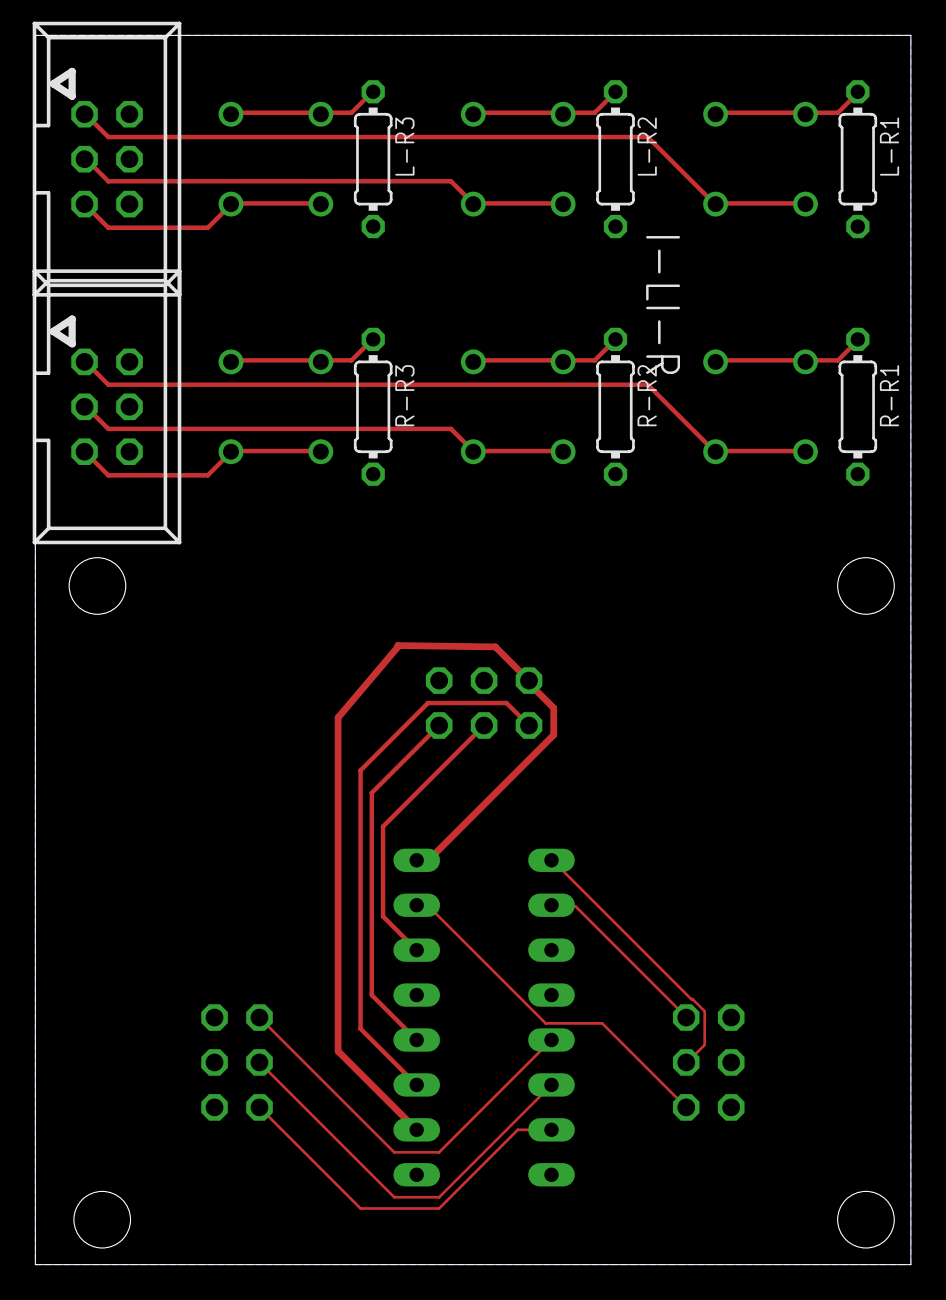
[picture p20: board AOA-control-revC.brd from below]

Board: 2 copper layers, 49.5 x 69.5 mm, 19 parts (8 on the bottom side), 23 nets.

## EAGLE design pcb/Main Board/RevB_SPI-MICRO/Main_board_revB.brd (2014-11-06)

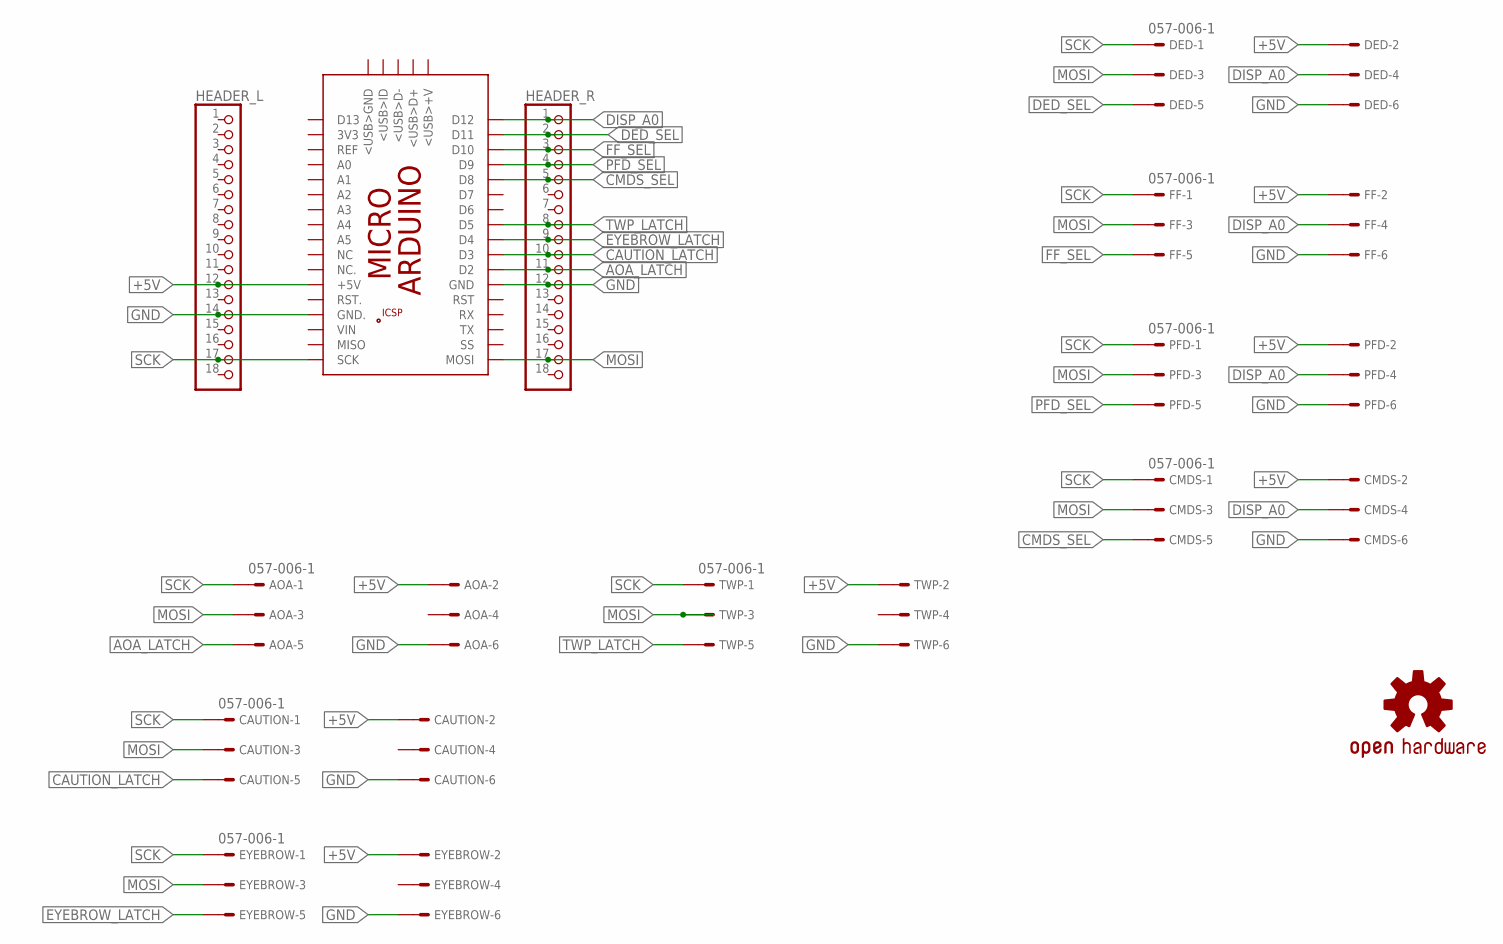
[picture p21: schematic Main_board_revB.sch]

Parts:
AOA: 057-006-1
CAUTION: 057-006-1
CMDS: 057-006-1
DED: 057-006-1
EYEBROW: 057-006-1
FF: 057-006-1
HEADER_L: PINHD-1X18; 1X18
HEADER_R: PINHD-1X18; 1X18
LOGO1: OSHW-LOGOL; OSHW-LOGO-L
PFD: 057-006-1
TWP: 057-006-1

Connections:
+5V: AOA.2, CAUTION.2, CMDS.2, DED.2, EYEBROW.2, FF.2, HEADER_L.12, PFD.2, TWP.2
AOA_LATCH: AOA.5, HEADER_R.11
CAUTION_LATCH: CAUTION.5, HEADER_R.10
CMDS_SEL: CMDS.5, HEADER_R.5
DED_SEL: DED.5, HEADER_R.2
DISP_A0: CMDS.4, DED.4, FF.4, HEADER_R.1, PFD.4
EYEBROW_LATCH: EYEBROW.5, HEADER_R.9
FF_SEL: FF.5, HEADER_R.3
GND: AOA.6, CAUTION.6, CMDS.6, DED.6, EYEBROW.6, FF.6, HEADER_L.14, HEADER_R.12, PFD.6, TWP.6
MOSI: AOA.3, CAUTION.3, CMDS.3, DED.3, EYEBROW.3, FF.3, HEADER_R.17, PFD.3, TWP.3
PFD_SEL: HEADER_R.4, PFD.5
SCK: AOA.1, CAUTION.1, CMDS.1, DED.1, EYEBROW.1, FF.1, HEADER_L.17, PFD.1, TWP.1
TWP_LATCH: HEADER_R.8, TWP.5

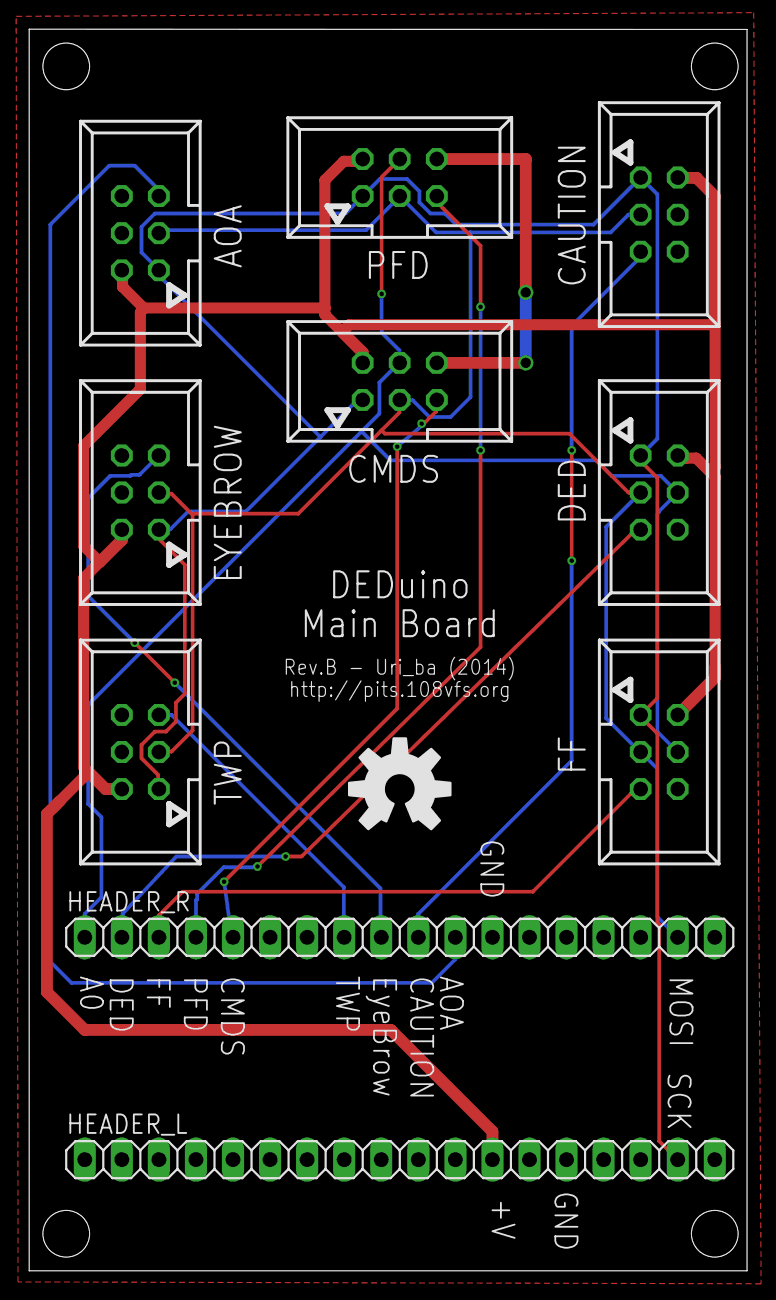
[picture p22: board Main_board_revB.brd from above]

Board: 2 copper layers, 49.2 x 85.1 mm, 11 parts (0 on the bottom side), 13 nets.

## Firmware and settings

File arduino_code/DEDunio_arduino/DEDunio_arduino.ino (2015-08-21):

//**********************************************************************//
//  Name    : DEDuino, Arduino displays for FalconBMS                   //
//  Author  : Uri Ben-Avraham                                           //
//  Date    : 21 Aug, 2015                                              //
//  Version : 1.2.0                                               //
//  License : MIT                                                       //
//  Notes   : Uncomment the DEFINE for the Arduino board in use         //
//          : Boards supported by this version:                         //
//          : Arduino Uno, Arduino Micro & Arduino Due                  //
//          : All Common Config options are found under "config.h"      //
//          :                                                           //
//          : Uncomment the DEFINE for the features you wish to use     //
//          : Features included in this version:                        //
//          : Displays: DED, FFI, PFD                                   //
//          : Lights: Indexers, Caution Panel                           //
//**********************************************************************//

#include <Arduino.h>
#include "config.h"
//*******************************************************************//
//  All configuration options are set via the "config.h" file        //
//  Please DO NOT edit code below this segment                       //
//  (Unless you know what you are doing - in which case.. have fun!) //
//*******************************************************************//


///*************** DO NOT EDIT BELOW THIS LINE WITHOUT INTENT! ***************//
///********** ALL COMMON CONFIG OPTIONS ARE FOUND THE config.h FILE **********//
#define MICRO_DELAY delayMicroseconds(250);
#ifdef ARDUINO_UNO
//////////////////////////////////////////////////////////////////////////
//  Arduino Uno                                                         //
//  SCK - Pin 13                                                        //
//  MISO - Pin 12 (not used in this project)                            //
//  MOSI - Pin 11                                                       //
//  SS - Pin10 (set to output and pulled high on setup)                 //
//////////////////////////////////////////////////////////////////////////
// Define SPI Pins
#define SCK 13
#define MISO 12
#define MOSI 11
#define SS 10
#endif

#ifdef ARDUINO_MICRO
//////////////////////////////////////////////////////////////////////////
//  Arduino Micro                                                       //
//  SCK, MISO, MOSI - all on dedicated pins no defines needed           //
//  use the Arduino Micro Pinout for reference                          //
//  https://www.arduino.cc/en/uploads/Main/ArduinoMicro_Pinout3.png     //
//////////////////////////////////////////////////////////////////////////
#endif

#ifdef ARDUINO_DUE
//////////////////////////////////////////////////////////////////////////
//  Arduino Due                                                         //
//  SCK, MISO, MOSI - all located on the ICSP header                    //
//  Only MOSI and SCK needs to be connected via the ICSP                //
//                                                                      //
//     1 - MISO | 0 0 | 2 - VCC                                         //
//     3 - SCK  | 0 0 | 4 - MOSI                                        //
//     5 - Reset| 0 0 | 6 - GND                                         //
//                                                                      //
//  NOTE:                                                               //
//  * Arduino Due has TWO (2) ICSP headers,                             //
//    Use the once closer to the ARM chip (not next to the power jack)  //
//  * Connect the Arduino Due using the "Native USB" port               //
//////////////////////////////////////////////////////////////////////////
#endif

///////////////////
//// Includes ////
//////////////////

// Serial Comm
#include "comms.h"

// displays
#ifdef Screens
  #include "U8glib.h"

  #ifdef FuelFlow_on
    #include "fuelflow_u8g.h"
    #include "fuelflow.h"
  #endif

  #if defined DED_on || defined PFD_on
    #ifdef Widefont
      #include "falconded_wide_u8g.h"
    #elif defined  MoonWidefont
      #include "falconded_moon_u8g.h"
    #else
      #include "falconded_full_u8g.h"
    #endif
  #endif

  #ifdef DED_on
    #include "ded.h"
  #endif

  #ifdef PFD_on
    #include "pfd.h"
  #endif
  
  #ifdef CMDS_on
    #include "cmds.h"
  #endif  
#endif

// LightPanels general config
// Light General
#ifdef Lights
  #ifdef USE_SPI
    #include <SPI.h>
    #include "lights_spi.h"
  #endif
  #ifdef USE_I2C
    #include <Wire.h>
    #include "lights_i2c.h"
  #endif
#endif

#include "internal.h"
///////////////////////////
//// Global Variables  ////
///////////////////////////

short Run = 0;

////////////////////
//// Functions ////
///////////////////

/////// Main Program /////////////
void setup() {
  // Init SPI/WIRE
#ifdef Lights
  #ifdef USE_SPI
    #ifdef ARDUINO_UNO
      pinMode(SS, OUTPUT);
      digitalWrite(SS, HIGH);
    #endif
    SPI.begin();
    #ifdef ARDUINO_DUE
      SPI.setBitOrder(MSBFIRST);
      SPI.setClockDivider(10);
    #else
      SPI.setBitOrder(LSBFIRST);
      SPI.setClockDivider(SPI_CLOCK_DIV2);
    #endif
  #endif

  #ifdef USE_I2C
    Wire.begin();
  #endif
#endif

delay(2000); // to allow screens to boot on power on defore init.

initSerial();

#ifdef FuelFlow_on
  initFF();
#endif
#ifdef DED_on
  initDED();
#endif
#ifdef PFD_on
  initPFD();
#endif

#ifdef Lights
  initLights();
#endif

 delay(POST_BOOT_BIT); // To allow user to verify everything is working correcly
}

void loop() {
  if (gotoSleep) {
    goDark();
  }
  
  // Fuel Flow
#ifdef FuelFlow_on
  readFF();
  drawFF();
#endif

  //DED
#ifdef DED_on
  readDED();
  drawDED();
#endif

  // Fuel Flow (again) - for refresh rate
#ifdef FuelFlow_on
  readFF();
  drawFF();
#endif
  // Indexers
#ifdef Indexers_on
  readAOA();
  lightAOA();
#endif

  // Non refresh critical function, run those alternating every loop.
  switch (Run) {
    case 0:
#ifdef PFD_on
      readPFD();
      drawPFD();
#endif
#ifdef Glareshield_on
      // Caution panel
      readGlareShield();
      lightGlareshield();
#endif
      Run = 1;
      break;
    case 1:
#ifdef CautionPanel_on
      // Caution panel
      readCautionPanel();
      lightCautionPanel();
#endif
      Run = 0;
  }
}

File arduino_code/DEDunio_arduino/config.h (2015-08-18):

///////////////////////////////////////////////////////////////////////
// Select Arduino Type - Uncomment correct board type                //
///////////////////////////////////////////////////////////////////////

//// Arduino Uno is the default as it is the most common - how ever it is NOT the recommended Arduino to use due to it's low amount of SRAM
//// Arduino Micro is considered the Minimum at this stage of the project
//// Arduino Due is the recommended Arduino in the long run (able to support future expansions)
//// There are two USB connections on the DUE, the NATIVE is the recommended, but in some cases driver issues may strike.

//#define ARDUINO_UNO
//#define ARDUINO_MICRO
#define ARDUINO_DUE_NATIVE
//#define ARDUINO_DUE_PROG



///////////////////////////////////////////////////////////////////////
// Module Defines                                                    //
// Uncomment The modules you want                                    //
// Without this settings Nothing will work                           //
// NOTE: Lights are going to be overhauled in V1.2                   //
///////////////////////////////////////////////////////////////////////

#define Screens //global enable screens
//#define Lights //global enable lights 


///////////////////////////////////////////////////////////////////////
// Sub-Module Defines                                                //
// Uncomment The modules you want                                    //
///////////////////////////////////////////////////////////////////////
#ifdef Screens
  #define DED_on
  #define FuelFlow_on
//  #define PFD_on 
#endif

#ifdef Lights
// Select transfer protocol (SPI or I2C)
// SPI is retained for legacy support I2C is preferable
  //#define USE_SPI
  #define USE_I2C
  
// Choose what to light up
// Available to both protocols
  #define Indexers_on
//  #define CautionPanel_on 

// Available only on I2C
//  #define Glareshield_on 
#endif


///////////////////////////////////////////////////////////////////////
// Sub-Module config                                                 //
// Uncomment The options you want to enable                          //
///////////////////////////////////////////////////////////////////////


////////// DED/PFL //////////
//// DED and PFL use the same font to save memory, you have two possible fonts.
//// "Wide" variant is more readable - Font my Alan "Cool Hand" Locatelli. (enabled by default) 
//#define Widefont
//// Another Variant based on Alan's Widefont. tweaked to be more lifelike
#define MoonWidefont

////////// FFI //////////
//*****************************************************************************************//
//** NOTE:                                                                               **// 
//** Due to performance issues, when using Arduino Uno,                                  **//
//** The RealFFI animation and the Bezel will be Automaticly disabled (check fuelflow.h) **//
//*****************************************************************************************//

//// Select the correct FFI display driver
//// SSD1306 dispaly drivers (such as the ones sold by Adafruit and sparkfun)
#define FFI_SSD1306

//// SH1106 display drivers (commonly found on ebay)
//#define FFI_SH1106

//** NOTE: Ebay bought displays are sometime mislabled and SH1106 displays may be SSD1306 (and vice versa) **//

/// Define bezel to draw FUEL FLOW and PPH on screen.
//// Bezel reduces FPS considerably - if you build a real Bezel, this option should be off
#define Bezel

//// Define RealFFI to draw "Real" FFI - when not defined a BMS style FFI is drawn
//// Real FFI animation requires more RAM available there for is not suitable for an Uno if DED/PFL are enabled
//// This feature will be automaticly disabled when using arduino Uno
#define RealFFI

////////// DEBUGGING //////////
//// Enable crosshair to help align text on screens ////
//#define crosshair

///*************** DO NOT EDIT BELOW THIS LINE WITHOUT INTENT! ***************//
// if any of the DUE options are enabled, enable the global DUE flag
#if defined(ARDUINO_DUE_NATIVE) || defined(ARDUINO_DUE_PROG)
  #define ARDUINO_DUE
#endif
///////////////////////////////////////////////////////////////////////
// Sub-Module Pinout configurations                                  //
// (Advanced settings - Don't change unless you mean it              //
///////////////////////////////////////////////////////////////////////

// Screen pins should be relativly static
#ifdef Screens
  #if defined(ARDUINO_UNO) || defined(ARDUINO_DUE)
    #define DISP_A0 9
    #define DED_SEL 8
    #define FF_SEL 7
    #define PFD_SEL 6
    #define CMDS_SEL 5
    #define EXT1_SEL 4
    #define EXT2_SEL 3
  #endif

  #ifdef ARDUINO_MICRO
    #define DISP_A0 12
    #define DED_SEL 11
    #define FF_SEL 10
    #define PFD_SEL 9
    #define CMDS_SEL 8
    #define EXT1_SEL 7
    #define EXT2_SEL 6
  #endif
#endif

// Adjust i2c addresses to fit your rig.
// you will probably need to adjust the lights_i2c.h and i2c_hardware.h to suit your specific board/hardware
#ifdef Lights
   #ifdef USE_I2C
       #define AoaAddr 0x20
       #define CpAddr  0x21
//       #define CpAddr2  0x22
       #define GsAddr  0x23

   #endif
// Retained for Legacy support - i2c is preferable.
   #ifdef USE_SPI
       #define AoaLatchPin 2 // AOA indexed
       #define CpLatchPin 3 // Caution Panels
   #endif
#endif

////////// INTERNAL VARS //////////
// How many seconds should go by before screens turn off after no response recived to the "I'm alive" signal
#define SLEEP_TIMER 120

// How many milliseconds go before the displays reset after initillizing (for user inspection)
#define POST_BOOT_BIT 4000

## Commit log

2014-11-29 Preparing V1.1
    Added new DED font by "cool hand"
    Added new new FFi font by "Moon"
    Added drawn FFi bezel - concept by "Topper Harly"
    Updated connector app to v0.0.0.2 - which solves some issues with DED
    chars being cropped
    :
    [AOA-control-revC.brd, AOA-control-revC.sch, Caution_Panel_control.brd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]
2014-11-29 PFD now uses new font as well by default. Adjusted horizontal offset for DED adn PFD. Reverted to Uno as default device
    [DEDunio_arduino.ino]
2014-12-03 Version 1.1.1 - initial commit New Fuelflow font - based on the Real MilSpec 33558 font. Thank you "Moon" and "AiRdAncE" for references, links and help. drawn Bezel is enabled by default - font is th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
    PFD now uses new font as well by default. Adjusted horizontal offset for DED adn PFD. Reverted to Uno as default device
    [DEDunio_arduino.ino, fuelflow.h]
2014-12-06 Another itteration for the FFI font and code - Thanks AiRdAncE
    [AOA-control-revC.brd, AOA-control-revC.sch, Caution_Panel_control.brd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]
2014-12-06 initial commit for v1.1.3 New mode called "RealFFI" - which animates the top two digits as well, blocking boxes are only drawn with the "Bezel" feature on to reduce FPS hit if using a real front plat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
    TODO: create a blank character for the FFtt (No 0 or 9) - adjust logic accordingly
2014-12-07 V1.1.3
    More improvemnts on FFI
    New FFI animation mode:
    "BMS" - FFI is rendered as the BMS one. animated Hundreds, the rest are jumping
    "RealFFI" - FFI is rendered as the Real thing, no 0 on higher numbers, rollover on all three top digits. (lower FPS)
    both modes include an optional Bezel drawn on top of the screen.
    font is set to be at the correct size with the Bezel off. Bezel on reduces the "window" size compared to the real FFI.
    Default FFI setting are "RealFFI" with "Bezel".
    Note that turning any of these options off will increase FPS and animation smoothness (Bezel being the more expensive of the two)
    New font is included, designed for maximum perfromance with minimum memory footpri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
    [DEDunio_arduino.ino, fuelflow.h]
2014-12-09 Fix FFI not rolling properly with DED disabled. Advanced version on ino file
    [DEDunio_arduino.ino, config.h, fuelflow.h]
2014-12-20 config.h refracting
    All important configuration options are now located on "config.h" file - no need to fuss around in the code
    Arduino Micro is now the default controller. Arduino Uno still works, but Bezel and RealFFI are autocratically disabled on it for performance reasons.
    Hopefully this will be the last of the SPI based light system releases. so please be aware when designing boards. - current AOA and Caution panel will still be available via SPI as they are now.
2015-01-25 Fix for Arduino Due not allowing FFi to work properly. updated included u8glib to v1.17
    [DEDunio_arduino.ino]
2015-02-09 small Endianess fix for Due, another tweak to sort out the FFI bug
    [DEDunio_arduino.ino]
2015-02-19 fixes for Main board design, added pdf schematic for the screen adapter
    [Main_board_revB.brd]
2015-02-19 initial commit for the 1.2 version - adding i2c support for lights
2015-03-29 1.2.0-alpha2 Display timeout and some bugfixes
    [DEDunio_arduino.ino, comms.h, config.h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]
2015-04-02 new PCB layouts
    [AOA-control-revC.brd, AOA-control-revC.sch, AOA-control-revD-sink.brd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]
2015-07-22 1.2.0-alpha3 u8glib updated to last version Fixed flicker and stutter issues on Due Adjusted for Arduino IDE 1.6.5
    [DEDunio_arduino.ino, comms.h, fuelflow.h]
2015-07-22 Connector App updated to v0.0.6 Fixes to minimize logic
2015-07-24 1.2.0-alpha4 Bug fixes Initial very raw implementation of CMDS - still need to tune font,position and data transfer. (strictly experimental)
    [DEDunio_arduino.ino, comms.h, config.h]
2015-08-12 Added FF adapter schematic in PDF format
2015-08-14 Disabled Moon's DED font due to a bug that I missed. it will be re-enabled once Font is fixed CoolHand's original Widefont is the default
    [config.h]
2015-08-16 Updated Moon's Widefont to fix char order error. tweaked spacing and re-enabled moon's as default.
    [config.h]
2015-08-16 1.2.0-alpha8 Glareshield no longer experimental and will be included in 1.2.0 TODO: Reference schematic.
    [DEDunio_arduino.ino, config.h]
2015-08-18 added eyebrow circuit reference
    [Glareshield-revA.sch]

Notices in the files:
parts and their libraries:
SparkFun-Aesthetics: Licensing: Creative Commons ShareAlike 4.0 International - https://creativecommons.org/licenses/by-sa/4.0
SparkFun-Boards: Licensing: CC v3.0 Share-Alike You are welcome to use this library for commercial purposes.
